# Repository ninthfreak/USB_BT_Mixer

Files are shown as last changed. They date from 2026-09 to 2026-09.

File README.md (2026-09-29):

# USB_BT_Mixer

A small box with two USB-C inputs and one Bluetooth audio output. Any USB-C host that supports USB audio sees each input as a normal USB sound card. The box mixes both inputs and streams the mix to any Bluetooth audio sink.

- **Architecture (start here): [`docs/architecture.md`](docs/architecture.md)**
- Decision log: [`docs/decisions.md`](docs/decisions.md)
- Design record: [`docs/HANDOFF.md`](docs/HANDOFF.md)
- Corrections since the handoff: [`docs/review-notes.md`](docs/review-notes.md)
- Design envelope (limits and extension points): [`docs/design-envelope.md`](docs/design-envelope.md)
- Viability review: [`docs/viability-review.md`](docs/viability-review.md)
- Parts list: [`hardware/BOM.csv`](hardware/BOM.csv)

Status: planning. Inputs: Waveshare RP2350-USB-C ×2, USB-C exposed directly through the enclosure (each needs an external Schottky to the shared rail). Bluetooth output: original ESP32 on a Waveshare ESP32-DEV-KIT-WROOM-32E-N4, powered from the rail via its `VSYS` pin. The ESP32 mixes and owns the audio clock. Configured from any browser via a page the box serves over USB; no case buttons. See [`docs/decisions.md`](docs/decisions.md). Firmware not started; the enclosure test coupon needs re-measuring for the new input board.

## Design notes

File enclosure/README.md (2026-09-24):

# Enclosure

## Status

| Part | State |
|---|---|
| USB-C wall + cradle **test coupon** (`usb_wall_test.scad`) | Ready to print. Two dimensions still need measuring. |
| Full enclosure | Not started. It waits on the coupon results and the TSA5001's dimensions. |

## Test coupon

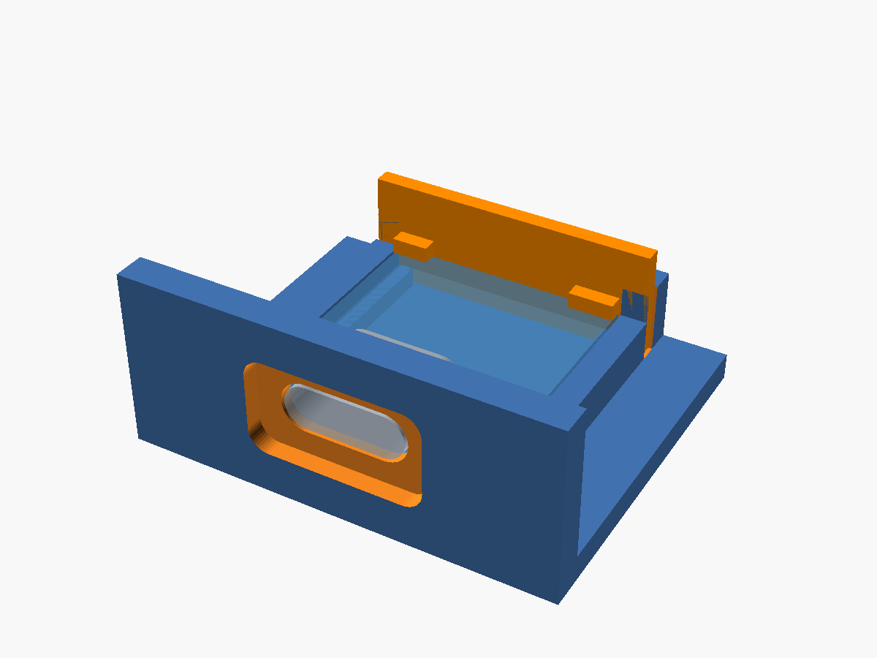
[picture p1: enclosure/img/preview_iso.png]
Coupon with clip, outside view


**What it's for:** a small print to check the port design before the full box.

- Does the QT Py's USB-C shell line up with the wall opening?
- Do real cables seat fully?
- Do plug-in and pull-out forces go into the printed parts instead of the board's solder joints?

**How it holds the board:**

| Force | Taken by |
|---|---|
| Pull-out (cable yanked outward) | The board's front edge presses against the wall's inside face |
| Push-in (plugging in) | The drop-in clip (`key`) behind the board's back edge |
| Up/down wiggle, front | The USB shell sitting in the wall opening |
| Up/down, back | The clip's two corner lips over the board top |
| Side to side | Pocket side walls, flush with the board top so the edge pads stay reachable for soldering |

**Cross-section through the port centreline.** Grey = cut faces, blue = coupon beyond the cut, orange = clip lip.

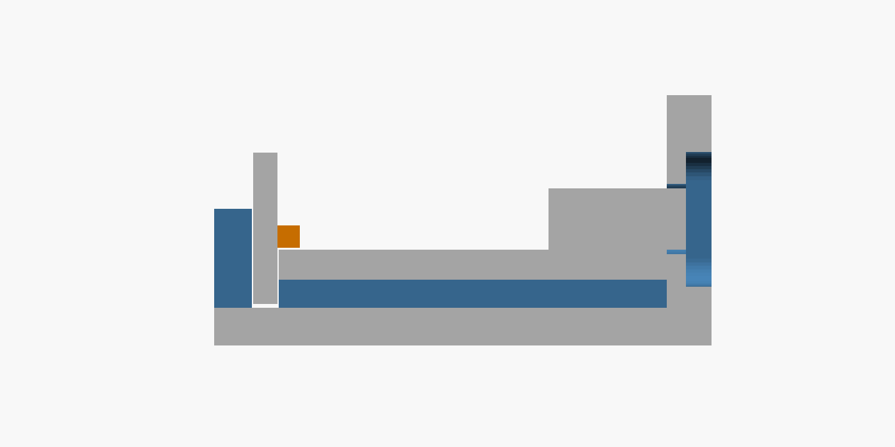
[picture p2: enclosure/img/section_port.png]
Section


## Before printing: measure two values

These aren't in Adafruit's board file. I used typical values; calipers on your board settle them.

| Parameter in `usb_wall_test.scad` | Current value | What to measure |
|---|---|---|
| `pcb_t` | 1.60 mm (assumed) | Board thickness, away from any parts |
| `usb_h` | 3.26 mm (typical top-mount shell) | USB-C shell height, board top to shell top |

After editing them:

1. Run `tests/check_fit.sh`. Every line should say `ok`, `clear` or `contact only`, and the exit code should be 0.
2. Re-export both parts:

   ```
   openscad -o stl/usb_wall_test_coupon.stl -D 'part="coupon"' usb_wall_test.scad
   openscad -o stl/usb_wall_test_key.stl    -D 'part="key"'    usb_wall_test.scad
   ```

   (`fit_checks.scad` repeats the board numbers; update them there too.)

Every other board dimension comes from Adafruit's Eagle `.brd` file: the outline, USB-C position, how far the shell overhangs the board edge (1.03 mm), and the part positions.

## Printing

| Setting | Suggestion |
|---|---|
| Files | `stl/usb_wall_test_coupon.stl`, `stl/usb_wall_test_key.stl` |
| Orientation | As exported. The coupon sits on its base; the clip lies on its back with the lips up. |
| Supports | None. The port opening and pocket are short bridges (~9–13 mm). |
| Material | PLA or PETG for the test. **Not** carbon-fibre-filled (that rule matters most near the antenna in the final box). |
| Layer height | 0.12–0.16 mm gives a cleaner port opening; 0.2 mm is fine for a first look. |
| Walls | 3 or more perimeters |

## Test steps

1. Lower the board into the cradle about 1.5 mm back from the wall.
2. Slide it forward until the USB shell enters the opening and the board edge touches the wall.
3. Drop the clip into the two slots behind the board.
4. Plug in several different cables, including one with a thick plug housing. Check each one:
   - Does it click fully in?
   - Does the board move?
   - Does the plug housing hit the wall before the plug is fully in?
5. Wiggle a plugged-in cable up, down and sideways. Watch whether the board flexes.

## Tuning parameters

| Symptom | Change |
|---|---|
| Board too tight or loose in the pocket | `fit` (default 0.20 per side) |
| Shell binds in the opening, or the gap looks sloppy | `hole_c` (default 0.25 per side) |
| Plug housing hits the wall before the plug is fully in | Raise `om_w` / `om_h` (13.0 × 7.2), or set `mouth_recess` negative |
| Clip too tight or loose in its slots | `key_fit` (default 0.15) |
| Board rattles up and down at the back | Reduce the gap between the clip lip and the board (`pcb_t + 0.1` in `key()`) |

## Files

| File | Contents |
|---|---|
| `usb_wall_test.scad` | Parametric model. Set `part` to `preview`, `coupon` or `key`. |
| `stl/` | Exported print files |
| `tests/check_fit.sh` | Collision checks: coupon, clip, board, USB shell, STEMMA connector, and the install path. Needs `openscad` and Python `trimesh`. |
| `img/` | Preview renders |

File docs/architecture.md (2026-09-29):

# System architecture

How the box works end to end. This is the single reference for firmware work. Decisions behind it are in `docs/decisions.md`; pins are in `hardware/wiring.md`.

**Status:** agreed design (2026-09-28; boards changed 2026-09-29). Nothing is built or tested yet.

```
                ┌────────────── RP2350-USB-C (×2, identical) ─────────────────┐
 Host ──USB──▶  │ sound card (UAC2) ──▶ audio buffer ──▶ PIO I2S out ─────────┼──DOUT──▶ ┐
                │                                         ▲ clocked by ESP32   │         │
                │ config page (USB network, HTTP) ◀─▶ relay ◀─▶ UART ────────┼──TX/RX─▶ │
                └──────────────────────────────────────────────────────────────┘         │
                                                      BCLK/LRCK ◀──────────────────────┤
                                                                                        ▼
                ┌────────────── ESP32-DEV-KIT-WROOM-32E-N4 ───────────────────────────────┐
                │ I2S0 / I2S1 in ──▶ per-input gain ──▶ sum ──▶ limiter ──▶ SBC ──▶ Bluetooth│
                │ UART1 / UART2 ◀─▶ command handler ◀─▶ settings (saved in flash)           │
                │ generates BCLK/LRCK (the only audio clock)                                 │
                └────────────────────────────────────────────────────────────────────────────┘
```

## 1. Roles

| Board | Job | Holds state? |
|---|---|---|
| **Waveshare RP2350-USB-C** (×2, one firmware image) | USB sound card for its host; sends that audio to the ESP32 over I2S, following the ESP32's clock; serves the configuration page over a USB network link; relays commands and replies between page and ESP32 | **No.** Stateless relay and web server. |
| **Waveshare ESP32-DEV-KIT-WROOM-32E-N4** | The only audio clock; receives both inputs; per-input gain, mix, limiter; Bluetooth A2DP source (SBC); pairing and reconnection; command handler | **Yes: the single source of truth** for all settings and pairings, saved in flash |

## 2. Audio path

1. **Host → input board:** USB audio (UAC2, asynchronous with a feedback endpoint), **44.1 kHz** stereo. **Constraint:** stock ESP-IDF's A2DP source is 44.1 kHz only, and nothing in the box resamples (review-notes #16). The audio arrives in 1 ms packets.
2. **Input-board buffer:** a TinyUSB FIFO held at about half full, roughly 2 ms (verified: TinyUSB `AUDIO_FEEDBACK_METHOD_FIFO_COUNT`).
3. **Input board → ESP32:** a PIO program shifts samples out on DOUT **on the ESP32's BCLK/LRCK edges**. The input board never generates audio timing.
4. **ESP32 input:** I2S0 (master) receives input board 1; I2S1 (slave, on looped-back clocks) receives input board 2. Both boards follow the same LRCK edges, so their samples arrive aligned.
5. **ESP32 processing:** host volume × box trim per input → sum in 32-bit → limiter → SBC encoder → Bluetooth.

**Clock synchronisation (no resampling anywhere):**

- The ESP32's clock drains each input board's FIFO at the ESP32's rate.
- TinyUSB's feedback endpoint reports the FIFO level to the host, which then adjusts its sending rate. Each host ends up locked to the ESP32's clock.
- The Bluetooth stack runs on the same ESP32 crystal.

**No host connected:** the input board is still clocked and sends zeros. That input simply contributes silence.

**Latency owned by the box:** input board FIFO ~2 ms + the ESP32's I2S DMA buffers (keep them small; to be measured) + SBC framing. The Bluetooth link and the headphones' buffer add the rest.

## 3. Control path

**Transport to the host: USB network adapter + a web page served by the box.**

- Each input board adds a USB network interface (CDC-NCM; CDC-ECM as fallback) beside its sound card, running lwIP with DHCP, DNS and an HTTP/WebSocket server. This is based on TinyUSB's `net_lwip_webserver` example.
- The host gets an address from the box. The box hands out **no default gateway**, so the host's internet traffic doesn't route through it.
- You open the page by address or name. Addresses differ per board, e.g. `192.168.7.1` for input 1 and `192.168.8.1` for input 2, plus a DNS name.
- The page is stored in the input board's flash and ships with the firmware, so page and firmware versions always match.
- Any browser works, Safari included. No internet, no other server, no permission prompts.

**Flow of one change:**

1. The page sends a command over the WebSocket, e.g. `set gain input=2 db=-6`.
2. The input board wraps it in a UART message and sends it to the ESP32.
3. The ESP32 validates and applies it, saves it if it's persistent, then **sends the new state out on both UARTs**.
4. Each input board forwards the state to any page it has open. Two pages (one per host) stay in sync.

**Events the input board sends unprompted:**

| Event | Purpose |
|---|---|
| Host volume / mute changed (the sound card's volume control) | The ESP32 applies it, so **all gain lives in one place** |
| Host mounted / unmounted / suspended | Status display; silence handling |
| FIFO underrun / overrun counts | Diagnostics |

**UART link (per input board):**

- About 1 Mbaud, 8N1.
- Framed messages: start byte, length, type, sequence number, payload, CRC.
- Commands that change state get an acknowledgement; the sender retries on timeout.
- Input-board pins: TX GP4, RX GP5 (RP2350 UART1). ESP32: UART1 (GPIO17/16) for input board 1, UART2 (GPIO19/18) for input board 2. Full map: `hardware/wiring.md`.

**Commands the ESP32 should support** (first pass, not final):

| Area | Commands |
|---|---|
| Mix | Per-input trim, per-input mute, master level, limiter on/off/threshold, ducking (optional) |
| Bluetooth | Scan, list results, connect, disconnect, forget, list paired devices, status (connected device, codec settings) |
| System | Get full state, firmware versions (ESP32 and both input boards), protocol version, reboot, reboot an input board into its bootloader |

## 4. Firmware updates

| Board | Method |
|---|---|
| Input board | The page (or `picotool`) sends "reboot to bootloader". The input board then appears as a USB drive; copy the new firmware file (UF2) onto it. |
| ESP32 | Its own USB-C (CH343P, auto-reset). Onboard D3 isolates it from the rail, so the box can stay powered while flashing. OTA over Wi-Fi possible later |

## 5. Risks, highest first

| Risk | Difficulty | Mitigation |
|---|---|---|
| Input-board PIO I2S slave timing | 5/10 | Logic analyzer; test with one board first |
| ESP32 I2S1 following I2S0's looped-back clocks | 5/10 | Test early, before the Bluetooth work |
| Sound card + network adapter as one USB device, across macOS, Linux and Android | 5/10 | Test on each host type early. Fallback: USB MIDI or USB serial for control; the UART protocol is unchanged. |
| RP2350 RAM/CPU for USB audio + lwIP + web server together | 3/10 | Measure; keep the page small and serve it from flash. The RP2350's 520 KB RAM (vs the RP2040's 264 KB) is why the input board changed |
| ESP32-A2DP volume handling | Low: supported (verified) | Use `A2DPNoVolumeControl` to avoid applying volume twice; handle passthrough VOL keys (review-notes #16) |

## 6. Suggested bring-up order

Each step is testable on its own:

1. ESP32 as I2S master → one input board sending a test tone → the ESP32 logs samples (proves the I2S slave path).
2. Add the second input board on I2S1 (proves the dual-input clocking).
3. ESP32 mix → Bluetooth A2DP to headphones with the test tones.
4. Input-board USB sound card → real host audio into the chain (proves feedback / clock lock).
5. UART protocol with a minimal command (e.g. set trim) sent from a serial terminal.
6. USB network + web page on the input board.
7. Shared power, hot-plug, enclosure.

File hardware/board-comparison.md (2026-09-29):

# USB-C RP2040 / RP2350 board comparison (power path)

Checked 2026-09-24; RP2350-USB-C added 2026-09-29.

> **Outcome:** the owner chose the **Waveshare RP2350-USB-C** on 2026-09-29, accepting that it needs an external Schottky per board. See `docs/decisions.md` and review-notes #20. The QT Py analysis below is kept because it still documents what the power path has to achieve.

**What this project needs from a board:**

1. A diode between USB VBUS and a header pin, so both boards can share one rail without connecting the two computers' 5V.
2. 5.1 kΩ CC resistors, so C-to-C cables supply power.
3. A reachable VBUS point, for "is a computer connected" sensing (optional, see below).
4. USB-C at the board edge, so the port can come straight through the enclosure wall.

**How each row was checked:**

- **Schematic:** read from the manufacturer's published schematic file (Eagle `.sch`, cloned from GitHub). The netlist shows the connections directly.
- **Text:** manufacturer text seen through search results. The schematic couldn't be fetched from this environment.
- **Unverified:** no source reached.

## Summary

| Board | VBUS → header diode | CC 5.1k | VBUS tap for sensing | Evidence |
|---|---|---|---|---|
| **Waveshare RP2350-USB-C** (chosen) | **No.** Both USB-C ports' VBUS go straight to the `VSYS` net and the `VSYS` header pin. No diode anywhere on the board. **Needs an external Schottky per board.** | **Yes** (R5/R6 on port 1, R10/R13 on port 2) | `VSYS` header pin (it is VBUS) | Schematic (github.com/waveshareteam/RP2350-USB-C) |
| **Adafruit QT Py RP2040** (superseded) | **Yes:** VBUS → D1 (NSR0320) → `+5V` pin | **Yes** (R12, R13) | JP2 solder-jumper pad (VBUS side) | Schematic |
| **Adafruit KB2040** | **Yes:** VBUS → fuse → D1 (NSR0320) → `RAW` pin | **Yes** (R1, R2) | SJ1 solder-jumper pad | Schematic |
| **SparkFun Pro Micro RP2040** | **Yes:** VBUS → PPTC fuse → D2 Schottky (280 mV) → `RAW` pin | **Yes** (R1, R3) | JP14 "USB solder pads" | Schematic |
| Adafruit Feather RP2040 | Yes, VBUS → MBR540 → VHI. But VHI isn't on a header; only the `USB` pin (raw VBUS) and `BAT` are. | Yes | `USB` pin | Schematic |
| SB Components Micro RP2040 | **No:** USB VBUS goes straight to the `5V` net and header pin | **No:** CC1/CC2 are unconnected in the schematic, so C-to-C cables won't supply power | `5V` header pin (it is VBUS) | Schematic (PDF from github.com/sbcshop/Micro_RP2040, v1.0, 2023-04-28) |
| Waveshare RP2040-Zero | **No.** The 5V pin *is* VBUS. | Unverified | 5V pin | Text |
| Seeed XIAO RP2040 | Unverified. Seeed advises adding your own diode when powering through the 5V pin, which suggests no onboard diode on that path. | Unverified | Unverified | Text (indirect) |
| Pimoroni Tiny 2040 | Unverified | Unverified | Unverified | None |

Solder jumpers JP2 (QT Py) and SJ1 (KB2040) join two *different* nets in the schematic, so they're open by default. That leaves the diode in circuit. Confidence ~90%.

## Consequences for this design

- On the QT Py, KB2040, and Pro Micro RP2040, the handoff's original power idea works as intended. **Tie the two boards' `+5V` / `RAW` pins together.** The onboard diodes combine both USB supplies and the computers never connect to each other.
- **The rail is about 4.25–5.2 V, typically ~4.65 V (estimate; review-notes #18)**: the host's VBUS minus cable drop minus one Schottky drop. Measure it on the built box. The TSA5001 voltage question from the handoff still stands.
- **Each host sees both boards' 10 µF input caps plus the added capacitor.** That's about 20 µF + 22 µF, over the USB 10 µF plug-in limit. Low practical risk (see review-notes #3).
- **VBUS sensing may not be needed.** With the cable unplugged, the board sees no USB frames, and TinyUSB reports "suspended".
  - Firmware can treat "not mounted or suspended" as "contribute zeros". That's the same behavior the handoff wanted from GPIO24.
  - Confidence ~75%. Sensing is still cheap to add from the solder-jumper pad: a 10k/20k divider to a GPIO.

## Recommendation (not a decision), as written 2026-09-24

**QT Py RP2040.** It's small (PCB outline 20.7 × 17.8 mm from the board file; the USB-C shell may overhang), has edge USB-C, and has all three power features confirmed from the schematic. It exposes about 11 GPIOs; this project needs about 6.

## What changed on 2026-09-29

The owner chose the **Waveshare RP2350-USB-C** instead, for its RAM. The comparison above ranks boards by power path alone, which is only one axis.

| | QT Py RP2040 | RP2350-USB-C |
|---|---|---|
| RAM | 264 KB | **520 KB** |
| Flash | 8 MB | 2 MB (W25Q16) |
| PIO blocks | 2 | 3 |
| Size | 20.7 × 17.8 mm | 33.0 × 17.5 mm (sourced, not measured) |
| USB-C ports | 1, at the edge | 2, one at each end. The inner one is unused and stays inside the case |
| Exposed GPIOs | ~11 | 15 (GPIO0–10, 26–29) |
| VBUS diode | Onboard | **External, owner-fitted** |

The deciding factor was RAM: fitting USB audio, lwIP and the web server on one chip is the highest firmware risk in `docs/architecture.md`, and doubling RAM attacks it directly. A missing diode is a part the owner already has; RAM is not.

**KB2040 or Pro Micro RP2040** if you want more pins or bigger solder pads. The Pro Micro's PPTC fuse is a nice extra. Their longer 33 × 18 mm Pro Micro footprint makes wall-mounting slightly easier.

## Sources

- Adafruit QT Py RP2040 design files: https://github.com/adafruit/Adafruit-QT-Py-RP2040-PCB
- Adafruit KB2040 design files: https://github.com/adafruit/Adafruit-KB2040-PCB
- Adafruit Feather RP2040 design files: https://github.com/adafruit/Adafruit-Feather-RP2040-PCB
- SparkFun Pro Micro RP2040 design files: https://github.com/sparkfun/SparkFun_Pro_Micro-RP2040
- SB Components Micro RP2040 schematic: https://github.com/sbcshop/Micro_RP2040
- Waveshare RP2040-Zero wiki: https://www.waveshare.com/wiki/RP2040-Zero
- Seeed XIAO RP2040 wiki: https://wiki.seeedstudio.com/XIAO-RP2040/

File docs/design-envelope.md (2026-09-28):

# Design envelope

The design's limits and extension points in one place. Written 2026-09-25.

**Baseline design (updated 2026-09-28):** 2× QT Py RP2040 (identical I2S slaves) → ESP32 Feather V2 (I2S clock master, mixer, A2DP source) → Bluetooth. One audio clock domain at 48 kHz, owned by the ESP32.

> **Sample rate is 44.1 kHz end to end** (constraint from ESP-IDF's A2DP source; review-notes #16). Any "48 kHz" below refers to the old TSA5001 baseline.
>
> Parts of this page were written for the earlier RP2040-master + TSA5001 baseline. Where it says "board A's clock", read "the ESP32's clock". The TSA5001-specific limits (48 kHz only, codec list) now describe the fallback only; the ESP32 A2DP source is SBC-only, and its sample rate is set in firmware.

**Evidence labels:** *verified* = checked against source, schematic or datasheet; *sourced* = third-party text; *estimate* = my judgment.

---

## 1. Hard limits of the baseline

| Limit | Value | Set by | Evidence |
|---|---|---|---|
| Sample rate | **48 kHz only** | TSA5001 | Sourced |
| USB speed | Full speed (12 Mbit/s) | RP2040 | Verified |
| USB audio bandwidth per input | Stereo 48 kHz at 16 or 24 bits fits easily (≤ 288 bytes per 1 ms frame; full-speed allows up to 1023) | USB 2.0 full-speed isochronous transfers | Calculated |
| Hosts that play 48 kHz material | The host OS converts it to 44.1 kHz itself; the box only offers 44.1 kHz | Host OS | Estimate: macOS, Linux and Android do this automatically |
| Bluetooth output | **One A2DP link, SBC/AAC/aptX family**, no LE Audio or broadcast (Auracast) | TSA5001 | Sourced (vendor list, not verified) |
| Bluetooth sinks at once | Presumably 1 | TSA5001 | Estimate |
| Latency, box's own path | ~2–3 ms | TinyUSB FIFO (~2 ms) + I2S hops (≈21 µs each) | Verified / calculated |
| Latency, end to end | Dominated by the Bluetooth link and the sink's buffer; unknown until measured | Sink + transmitter | — |
| Supply rail | About 4.25–5.2 V, typically ~4.65 V (host VBUS minus cable drop minus one Schottky diode) | Board power paths, USB-C VBUS range | Verified topology; voltage is an estimate (review-notes #18) |
| Power available | Whatever one host's port supplies, since one host may power everything | USB spec: 500 mA for USB 2.0, 900 mA for USB 3.x, 1.5–3 A for USB-C current modes | Sourced (USB spec) |
| Audio back to hosts (microphone) | None | A2DP carries audio one way only; no capture stream is defined | Verified (design) |
| Controls | Each host's own volume slider only | Design | — |

---

## 2. The rule behind most boundaries: one clock domain

Everything mixed digitally must run on **board A's clock**.

| Source type | Fits? | Why |
|---|---|---|
| USB input through another RP2040 | **Yes** | The host follows A's clock through USB feedback. |
| ADC (analog input) | **Yes** | The ADC follows A's clocks. It needs a master clock, which requires the 61.44 MHz clock change. |
| Anything with **its own clock**: S/PDIF/optical input, a Bluetooth *receiver*, network audio, a second I2S master | **No, not without an ASRC** | Two independent clocks drift apart, so one stream has to be resampled (asynchronous sample-rate conversion). That means a hardware ASRC chip or software resampling; difficulty 6–7/10. |

---

## 3. Extension points

| Extension | What it takes | Clock change? | Difficulty | Confidence | Main risk |
|---|---|---|---|---|---|
| **More USB inputs** | Another RP2040 per input, chained before board B. Each adds 1 frame (≈21 µs). | No | 3/10 per board | ~80% | Board A's clock line fans out further; power budget |
| **Analog line input** | 3.5 mm jack → PCM1808 ADC (following A's clocks) → board B's chain input; 12.288 MHz master clock from board A; fix sample scaling; gain in firmware | **Yes: 76.8 → 61.44 MHz** | ~4/10 | ~70% | Ground-loop hum; ADC input range on a 4.25–5.2 V supply (unverified) |
| **Analog line output** | PCM5102A DAC wired in parallel with the TSA5001; 3.5 mm jack | No | ~2/10 | ~85% | Hum into mains-powered gear; wired output is ~150–250 ms ahead of Bluetooth |
| Headphone output | Analog line output + headphone amplifier | No | ~3/10 | ~80% | Same as above |
| Different Bluetooth output stage | Anything that accepts board A's I2S: ESP32 (SBC only), TS3086-based module (if the firmware suits), nRF5340 (LE Audio) | No | 4–8/10 | 30–60% | Firmware and interop; see `viability-review.md` §3b |
| USB Bluetooth dongle (aptX Adaptive) | Third RP2040 as USB audio **host**; board A's clock trimmed to follow the dongle | No, but A's clock becomes adjustable | 7/10 | ~40% | RP2040 host playback unproven; clock-following loop |
| Physical volume knob | Potentiometer → a spare analog pin, or a digital encoder | No | 2/10 | ~85% | **Pin conflict:** A0–A3 (the analog pins) are used for I2S in the current pin map |
| Status LED | Onboard NeoPixel, **not** red/green-coded | No | 1/10 | ~95% | — |

---

## 4. Not reachable without a redesign

| Goal | Why not |
|---|---|
| Sample rates other than 48 kHz end to end | TSA5001 is 48 kHz only |
| Latency below what the sink's buffer allows | The sink's firmware sets it; only a lower-latency codec or transport negotiated with that sink helps |
| Microphone / calls through the headphones | A2DP carries audio one way only |
| Several Bluetooth sinks at once | Not with the TSA5001 |
| Mixing unsynchronised digital sources | Needs an ASRC (§2) |
| Running with no host connected | No battery; the box gets its power from the hosts |

---

## 5. Resource budget, board A (current pin map)

| Resource | Used | Free | Notes |
|---|---|---|---|
| Header GPIOs (11, plus 2 on the STEMMA QT connector) | BCLK, LRCK, DOUT, DIN, UART TX | ~6–8 | GP24/25 are the clock-output-capable pins needed for an ADC master clock |
| PIO state machines (8) | ~2–3 (I2S out, I2S in) | ~5 | A separate DAC data line would use one more |
| CPU | TinyUSB + mixing + limiter | Large margin (estimate) | ~1,600 cycles per 48 kHz frame at 76.8 MHz, ~1,280 at 61.44 MHz |

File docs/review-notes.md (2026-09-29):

# Review notes on the handoff

Checked 2026-09-24. These are corrections and added risks. The items are *not* yet verified on hardware.

## 1. Board choice: the handoff says Pico, the plan was a USB-C RP2040 board

- The handoff specifies a micro-USB Raspberry Pi Pico plus panel extensions. The real plan was a **USB-C RP2040 board** (Waveshare, Adafruit, or Seeed), with its **port exposed directly through the enclosure wall**. No extension cables.
- Anything in the handoff that depends on the Pico board is suspect:
  - **Power sharing:** the Pico has an onboard VBUS → VSYS Schottky. Other boards may tie their 5V pin straight to VBUS. If so, tying the two boards' 5V pins together **connects both computers' 5V rails**. Each board then needs its own external Schottky.
  - **VBUS sense:** GPIO24 is Pico-only. Plan on a resistor divider from each board's VBUS (before any diode) to a spare GPIO.
  - **CC resistors (5.1 kΩ Rd):** needed for C-to-C cables to supply power. Most USB-C boards have them. Verify per board.
- Enclosure impact: the board's USB-C receptacle takes the plug forces directly. The enclosure must back the board so that plugging and unplugging don't load the solder joints.

## 2. System clock: 153.6 MHz is an overclock

| Clock | × BCLK | RP2040 (Pico) rating 133 MHz | RP2350 (Pico 2) rating 150 MHz |
|---|---|---|---|
| 76.8 MHz | 25 | In spec | In spec |
| 153.6 MHz | 50 | Over spec (SDK 2.1.1+ treats up to 200 MHz as supported, ~85% sure of that) | ~2% over spec |

- **Recommendation:** start at **76.8 MHz** (VCO 768 MHz, /5 /2). It divides evenly, and it's in spec on both chips.
- A slave PIO still gets ~12 cycles per BCLK half-period, which is enough to follow edges.
- Move to 153.6 MHz only if CPU time runs short.
- Note: jitter here doesn't affect sound quality (the TSA5001 re-encodes digitally). The integer divider mostly helps cleaner analyzer captures.
- Confidence: ~80% that 76.8 MHz leaves enough CPU for TinyUSB plus mixing. The load is light (48k stereo frames/s).

Full list of integer options from the 12 MHz crystal (≤ 210 MHz): 30.72, 46.08, 61.44, 76.8, 153.6 MHz.

## 3. Rail capacitance vs. the USB spec

- USB 2.0 caps plug-in capacitance at **10 µF** unless you limit inrush current. The handoff says ≤ 47 µF.
- Each host sees all the VSYS capacitance through its diode: Pico A's + Pico B's onboard caps + the added capacitor.
- **Practical risk: low.** Most hosts tolerate it. At worst you'd see a brief brown-out or a port-overcurrent message on plug-in.
- **Recommendation:** start at 22 µF. Go up only if the TSA5001 drops out under load.

## 4. Firmware: only connect USB when VBUS is present

- Pico B gets power from Pico A's side even when its own cable is unplugged.
- Firmware should call `tud_connect()` only while GPIO24 reads high, and `tud_disconnect()` when it goes low. Otherwise it drives the D+ pull-up into a dead cable.
- Low risk either way, but it's cleaner.

## 5. Pico 2 (RP2350) erratum E9

- On RP2350 A2 silicon, an input pin with the **internal pull-down** enabled can latch at ~2 V.
- It doesn't affect pins driven by Pico A or tied hard to GND.
- If you use Pico 2 boards, **disable internal pull-downs** on the I2S input pins.
- Confidence: ~85% that it's harmless in this design with pulls off.

## 6. RP2040-Zero power path (board under consideration)

- **Source-verified:** on the RP2040-Zero, the **5V pin is wired straight to USB VBUS**, with no diode. The board has no power-path circuitry, only the ME6211 3.3 V LDO. (Waveshare wiki text, seen through search results. The schematic PDF couldn't be fetched from this environment.)
- **Consequence:** the handoff's "tie the two VSYS pins together" becomes "tie two computers' VBUS together". **Don't do it.**
- **Consequence 2:** Board A is the only clock source and the only output. If only Board B's cable is plugged in, Board A must still get power, so a shared rail is required.
- Candidate fixes are in the chat log and not yet chosen. Test to run: power one Zero's 3V3 pin from a bench supply with USB unplugged, and measure the 5V pin. That shows whether the ME6211 back-feeds VBUS.
- **CC resistors:** not verified. Test with a C-to-C cable into a laptop.

## 7. Board comparison

See `hardware/board-comparison.md`. The QT Py RP2040, KB2040, and Pro Micro RP2040 all have an onboard VBUS diode and CC resistors (confirmed from schematics). The shared-rail power design works on them as originally intended.

## 8. Board chosen: Adafruit QT Py RP2040

Sections 4–6 above that assume a Pico or Pico 2 are superseded:

- GPIO24 VBUS sense → optional divider from JP2, or firmware-only detection (see `hardware/board-comparison.md`).
- Erratum E9 (#5) → moot. The QT Py is RP2040, not RP2350.
- Wiring → `hardware/wiring.md`.

## 9. Volume control: omitting it likely breaks macOS

- The handoff says to leave the volume control out of the USB descriptor and let the OS apply software volume.
- **Windows** does that. **macOS generally doesn't.** It greys out the volume slider for devices that expose no volume control (the same as with HDMI). Confidence ~85%.
- **Recommendation:** keep the Feature Unit (volume + mute), as TinyUSB's `uac2_speaker_fb` example already does, and apply the gain per board in firmware. Each computer's slider then still sets its level in the mix.
- Difficulty 2/10.

## 10. TinyUSB feedback: verified against current source

Checked against the TinyUSB master branch cloned 2026-09-24:

- The `uac2_speaker_fb` example exists.
- The buffer-fill method is `AUDIO_FEEDBACK_METHOD_FIFO_COUNT`, set in `tud_audio_feedback_params_cb()`. It holds the FIFO at half full and adds about 2 ms of delay. The header comment says it's tested on Windows, Linux, and macOS.
- **The Windows feedback-format worry is mostly handled.** For UAC2, TinyUSB sends 16.16 feedback in 4 bytes, which is the format Windows requires.
- Keep "test on Windows" as a milestone, but it's lower risk than the handoff implied.

## 11. Debug output: use the UART, not USB serial

- The handoff's milestone 1 logs over "serial". On the QT Py, the only USB port is the audio port.
- **Recommendation:** log on UART TX (GP20) to a 3.3 V USB-serial adapter. That keeps the audio USB descriptor simple.
- USB CDC plus audio (composite) also works, but it adds another thing to debug on Windows.

## 12. Smaller gaps

| Item | Note | Risk |
|---|---|---|
| Firmware updates with the box closed | The BOOT button is inside the box. Add a TinyUSB reset interface so `picotool reboot -u` (or a 1200-baud touch) enters the bootloader. Consider a pinhole over the button as a backup. | Low |
| NeoPixel | Drive GP11 low to keep it off (a few mA and stray light), or use it as a status LED, **not** red/green-coded. | Low |
| USB suspend current | If one host sleeps while the other plays, the diode-OR can still draw ~100 mA from the sleeping host. That's technically over the 2.5 mA suspend limit. Hosts rarely enforce it. | Low |
| Ground tie | The box joins both computers' grounds. The box's audio is digital so it's fine here, but either computer's *own* analog outputs could pick up hum. | Low |
| Per-stage delay | Each slave stage adds 1 frame (≈21 µs). Negligible. | None |
| PCM5102A test board | Many modules need SCK tied to GND (a solder jumper) to run without MCLK. Check before milestone 2. | Low |

## 13. ESP32 switch: power and pin effects (2026-09-28)

- **Power:** the ESP32 streaming Bluetooth adds roughly 100–150 mA (estimate), more with Wi-Fi. The box total is about 150–300 mA (estimate), still within one USB 2.0 port's 500 mA. Raise `bMaxPower` in each RP2040's USB descriptor to about 300–400 mA.
- **Feather V2 feed:** superseded by #14 (rail → `BAT` pin, no diode).
- **Pins:** the QT Py's only UART pair (GP20 TX / GP5 RX) is needed for the RP2040 → ESP32 control link. RP2040 debug logging moves to a PIO-based serial output on a spare pin. This supersedes #11. `hardware/wiring.md` needs updating once the mixing location is decided.

## 14. Feather V2 power path (verified from Adafruit's schematic, 2026-09-28)

Source: `Adafruit ESP32 Feather V2.sch` from github.com/adafruit/Adafruit-ESP32-Feather-V2-PCB.

| Net | Connected to |
|---|---|
| VBUS (Feather's USB-C) | `USB` header pin **directly**, CP2102N USB-serial chip, MCP73831 charger input, Schottky D4 (MBR540) → VHI |
| VBAT | `BAT` header pin, JST socket, charger output, P-MOSFET Q3 → VHI |
| VHI | Input to both AP2112 3.3 V regulators |
| Q3 gate | VBUS (battery path turns off when USB is present) |
| CC1 / CC2 | 5.1 kΩ each |

**Decision input: feed the shared rail into `BAT`, not `USB`. No external diode.**

- **Feeding `USB` would put the rail on the Feather's own USB-C VBUS.** A laptop plugged in for flashing would then see voltage already present (USB-C sources expect ~0 V before switching on), and an unpowered laptop port would be back-fed.
- **Feeding `BAT`:** the rail reaches the regulator through Q3 (and its body diode). Nothing reaches VBUS, so flashing cables behave normally. When a flashing cable is plugged in, Q3 switches off and USB powers the ESP32.
- **Charger behaviour:** with the box powered, the rail (typically ~4.65 V; range in #18) is above the charger's 4.2 V target, so it doesn't charge. With the box *unpowered* and a flashing cable in the Feather, the charger sources ≈200 mA into the rail. **Correction (see #17):** that's probably not enough to run the whole box, so the QT Pys may brown out during bench flashing.
- **Limits to respect:** never connect a LiPo to the JST socket. The rail on `BAT` exceeds a LiPo's 4.2 V maximum. The ESP32's battery-voltage input (through the 200 kΩ divider) will read the rail voltage, which is a useful diagnostic.
- Confidence ~80%. The topology is verified. The charger's reverse behaviour and its absolute-maximum VBAT rating (believed ≥6 V) are from memory.

## 15. Architecture change: ESP32 hub (2026-09-28)

These parts of the handoff no longer apply: RP2040 A as clock master and mixer; the `ROLE_MASTER_LAST` / `ROLE_SLAVE` split; the TSA5001 output.

- **RP2040 firmware:** one role on both boards. USB audio in → I2S slave out, plus the UART control relay. Each board keeps a DIN chain input for future expansion.
- **RP2040 system clock:** no longer needs to divide evenly into the audio clock, because the RP2040s receive the clock instead of making it. Its only job is to follow BCLK edges reliably (76.8 MHz or 125 MHz both fine; estimate).
- **ESP32:** I2S0 master (receives QT Py 1) and I2S1 slave on looped-back clocks (receives QT Py 2). The mix, per-input gain and limiter run in ESP32 firmware. The ESP32's audio PLL (APLL) should give an accurate 48 kHz (estimate).
- **ESP32 I2S DMA buffering** adds latency. Keep the DMA buffers small; to be measured.
- **Analog input option (if revisited):** a PCM1808 master clock would now come from the ESP32 (which can output a master clock on GPIO0/1/3 only, ~80% confident; none of those is on the Feather's headers). Revisit if needed.

## 16. ESP32-A2DP library and ESP-IDF A2DP source: verified from source (2026-09-28)

Sources: `pschatzmann/ESP32-A2DP` at commit 35bace5 (2026-09-22); `espressif/esp-idf` master (2026-09-25), `components/bt/host/bluedroid/btc/profile/std/a2dp/bta_av_co.c`.

### Reconnection: supported

- The last connected headphone address is **saved in flash** (NVS key `src_bda`) on connect, and loaded again at start.
- `set_auto_reconnect(true, retries)` retries that address after a disconnect and on a periodic heartbeat. When the retries run out, it falls back to scanning.
- **Scanning only connects to a device your code accepts**, through a name list or `set_ssid_callback(...)`. Our firmware should use the callback to *collect* scan results for the web page rather than auto-accepting.
- A deliberate `disconnect()` suppresses auto-reconnect. "Forget" = clear the saved address (`clean_last_connection`), plus remove the bond with ESP-IDF's `esp_bt_gap_remove_bond_device` (ESP-IDF API; not checked in this pass).

### Headphone volume buttons: supported, with one fix needed

Headphones report button presses in one of two ways:

| How the headphones report it | What the library does | What our firmware must do |
|---|---|---|
| **Absolute volume** (AVRCP 1.4+): the headphones change their own volume and notify the source | Receives the notification, echoes the value back, **and also scales the audio samples itself** (default `A2DPDefaultVolumeControl`) | **Install `A2DPNoVolumeControl`** (`set_volume_control`). Otherwise the volume is applied twice: once in the headphones and again in the ESP32, so it drops off far faster than intended (estimate). Report the level to the page. |
| **Passthrough VOL_UP / VOL_DOWN keys** (headphones act as a remote) | Passes key codes to `set_avrc_passthru_command_callback` only; **takes no action itself** | Handle the keys: step the box's master gain |
| Headphones set the *source's* volume directly (rare) | Logged, ignored | Nothing, unless a real headphone needs it |

If the headphones do neither, they adjust their own volume locally, and nothing is needed.

### Sample rate: **44.1 kHz only** (ESP-IDF limitation)

- ESP-IDF's A2DP **source** advertises SBC at **44.1 kHz only** (`bta_av_co_sbc_caps.samp_freq = A2D_SBC_IE_SAMP_FREQ_44`). Its sink side offers 48 and 44.1 kHz. The library README also says the source expects 44.1 kHz PCM.
- **Consequence: the whole box runs at 44.1 kHz. This is a constraint, not an option.** The ESP32 I2S master runs at 44.1 kHz, and the QT Pys advertise 44.1 kHz on USB. The hosts resample 48 kHz material themselves (macOS, Linux and Android do this automatically; estimate ~90%). The box itself still needs no resampling.
- Patching ESP-IDF's capability table to offer 48 kHz is an experiment, not a design option: it needs a maintained patched ESP-IDF and is untested (~50%). Resampling 48 → 44.1 kHz in the ESP32 would break the one-clock, no-resampling design rule.
- The earlier 48 kHz figures (the handoff's TSA5001 plan, the RP2040 clock maths) no longer apply to this design.

### Other findings

- **Headphone latency reporting:** ESP-IDF ≥ 5.3 delivers `ESP_A2D_REPORT_SNK_DELAY_VALUE_EVT` when the headphones report their own delay. The library only logs it, but our firmware can show it on the page. It helps with the latency question.
- **Codecs:** the library's AAC support is for the *receiving* (sink) side only. The source is SBC.
- **Build:** usable as an ESP-IDF component (CMakeLists present). It lists `arduino-audio-tools` as a required component despite the README saying there are no other dependencies. That's minor build friction.
- **Licence ambiguity:** the LICENSE file is Apache-2.0, but a CMakeLists comment says GPLv3. Irrelevant for a personal build; check before distributing anything.

## 17. Feather V2 on the rail: full power check (2026-09-28)

| Check | Result | Evidence |
|---|---|---|
| Path: rail → `BAT` → Q3 P-MOSFET → VHI → AP2112 3.3 V regulator | Works. Q3's gate sits at VBUS (0 V without the Feather's own USB cable), so Q3 turns fully on. | Schematic (verified) |
| Regulator input limit | Rail ~4.25–5.2 V (#18) vs AP2112 maximum 6 V. OK. | AP2112 datasheet via search |
| Regulator headroom | Needs ≥ ~3.55 V in (250 mV dropout). Rail gives ~0.7 V of margin at its low end (4.25 V), ~1.1 V typical. OK. | Datasheet via search + calculation |
| Regulator heat | ESP32 streaming ~150–250 mA (estimate) × (rail − 3.3 V): ≈ 0.2–0.35 W typical, up to ≈ 0.3–0.5 W at the 5.2 V high end, in a SOT-23-5. **Same as the Feather's own USB power:** that path is also VBUS minus one Schottky (D4), so the regulator sees the same voltage either way. Not re-checked against the AP2112's thermal resistance. *(Corrected: an earlier version said the rail was "better than USB's 5 V"; the regulator never sees 5 V from USB either.)* | Estimate + schematic |
| Battery-voltage monitor (200 kΩ divider to an ADC pin) | Reads half the rail: ~2.1–2.6 V at the pin. Safe; a free rail-voltage readout. | Schematic + calculation |
| **MCP73831 charger chip (U3) with the rail (~4.25–5.2 V) on its battery pin** | **Soft spot.** Its absolute-maximum table lists all pins as −0.3 V to (VDD + 0.3) V. Taken literally, that's also exceeded by every battery-powered Feather with no USB (4.2 V battery, VDD = 0), so it can't be the whole story. The chip is designed to sit on a battery while unpowered. But the rail is typically ~0.45 V and at worst ~1.0 V above the 4.2 V it's designed around (#18), and I couldn't reach the full datasheet to check. **~75% harmless (estimate; lowered from 80% once the rail's high end was worked out).** | Datasheet row via search; full datasheet blocked |
| Charger back-feeding the rail when the box is unpowered and a flashing cable is in the Feather | The charger sources ~200 mA (R4 = 5.1 kΩ) into the rail. That's **probably not enough to run the QT Pys too** (box ≈ 150–300 mA), so they may brown out and restart during bench flashing. Harmless but messy. **Corrects #14**, which said it would "power the whole box". The ESP32 itself is fine; it's powered from USB through D4. | Calculation |

**Ways to remove the charger concern:**

| Option | Effect | Difficulty | Recommendation |
|---|---|---|---|
| **A. Remove the charger chip (U3, SOT-23-5)** from the Feather | Removes both the voltage question and the back-feed. The Feather works normally without it; it only charges batteries. | 2/10 with hot air or two irons; permanent | **Recommended** (not a decision) |
| B. One Schottky diode, rail → `BAT` | BAT drops by another ~0.3–0.4 V: typically ~4.3 V, range ~3.9–4.9 V. Regulator still has headroom at the low end. The back-feed is blocked | 1/10 | Reduces the concern but doesn't remove it. Still a non-battery source on `BAT` with the charger fitted, which Adafruit warns against (#19) |
| C. External 3.3 V regulator into the Feather's `3V` pin, Feather `EN` pulled low | Charger and `BAT` unused entirely | 3/10 | Works, but the ESP32 then can't be flashed unless the box is powered |
| D. Leave as is | **Against Adafruit's guidance** (#19). Earlier rated ~75% fine; that estimate no longer stands | 0/10 | Not recommended |

## 18. Rail voltage: derived, not assumed (2026-09-28)

**Correction.** Every doc called the shared rail "~4.6–4.8 V". That figure came from the handoff, was never derived, and was presented as the range. It is only a typical value. Where "4.6–4.8 V" or "4.7 V" still appears, read the range below. `HANDOFF.md` is left verbatim as the historical record.

**Rail = host VBUS − cable drop − QT Py diode drop (D1, NSR0320).** The pin is labelled `5V` but is never 5 V from a 5 V host.

| Input | Value | Evidence |
|---|---|---|
| Host VBUS (USB-C, vSafe5V) | 4.75–5.5 V allowed; most hosts ~5.0–5.1 V | Range: sourced (USB Type-C spec, via search). Typical: estimate |
| Cable drop at ~0.15–0.3 A | ~0.05–0.1 V | Estimate |
| NSR0320 forward drop | 0.24 V typ at 10 mA; 0.5 V max at 900 mA | Sourced (datasheet figures via search; onsemi PDF blocked here) |
| NSR0320 drop at the box's current (~0.15–0.3 A, estimate) | ~0.3–0.4 V | Estimate, interpolated between the two datasheet points |

| Case | Calculation | Rail |
|---|---|---|
| Low: host at spec minimum, long cable, full box load through one diode | 4.75 − 0.1 − 0.4 | **~4.25 V** |
| Typical | 5.05 − 0.05 − 0.35 | **~4.65 V** |
| High: host at spec maximum, light load | 5.5 − 0 − 0.3 | **~5.2 V** |

**Result: about 4.25–5.2 V, typically ~4.65 V. Confidence in the range ~75%** (the diode curve between 10 mA and 900 mA and real host voltages are the soft parts).

When both hosts are connected, the host with the higher VBUS supplies most or all of the current (the two diodes act as an OR). Current doesn't split evenly.

**Effects of the wider range:**

| Part | Low end (4.25 V) | High end (5.2 V) |
|---|---|---|
| Feather AP2112 regulator (needs ≥ ~3.55 V, max 6 V) | OK | OK |
| Regulator heat | Lower | Higher, but equal to the Feather's normal USB power (VBUS − D4) at the same host voltage |
| Feather battery monitor ADC (half the rail) | ~2.1 V | ~2.6 V; safe |
| MCP73831 charger (U3) battery pin | Concern mostly gone | ~1.0 V above 4.2 V; the concern gets worse (see #17 options) |
| QT Py's own 3.3 V regulator | Not re-checked here; it's the board's normal USB-powered condition | Same |

**To verify:** measure the rail with a multimeter on the built box: one host, then both, at idle and while streaming Bluetooth. Record it in `docs/` as a test log.

Sources: [USB Type-C Spec R2.0](https://www.usb.org/sites/default/files/USB%20Type-C%20Spec%20R2.0%20-%20August%202019.pdf); [onsemi NSR0320MW2T1 datasheet](https://www.onsemi.com/download/data-sheet/pdf/nsr0320mw2t1-d.pdf).

## 19. Adafruit's guidance on powering a Feather through `BAT` (2026-09-28)

**Adafruit advises against it.** Their Feather power-management pages carry the same warnings across the family:

- "Do not use alkaline or NiMH batteries and connect to the battery port - this will destroy the LiPoly charger" (and, on several pages, "there's no way to disable the charger").
- "The Feather is not designed for external power supplies."
- Their suggested alternatives: USB power (wall adapter or USB battery pack), or a 5 V source wired to a USB cable. Feeding 3.3 V into the `3V` pin is listed as technically possible but **not recommended**.

| Claim | Evidence |
|---|---|
| The warnings above appear on Adafruit's Feather power-management pages (ESP32-S2, ESP32-S3, HUZZAH32, RP2040, M0, 32u4 and others) | Sourced: search-result text; learn.adafruit.com is blocked here, so not read directly |
| The ESP32 Feather V2 page carries the same warning | **Not confirmed.** The V2 text pasted by the owner has a "Danger:" box whose contents were stripped. Very likely the same family text (estimate ~85%) |
| Why the charger is destroyed | **Not stated by Adafruit.** Unknown whether a 4.25–5.2 V supply triggers the same failure as a 3–4.5 V alkaline pack |

**What this changes:**

- The failure Adafruit names is **the charger chip (U3)**, which is exactly the part #17 flagged. Their warning backs up that concern and replaces my ~75% estimate.
- **Option A (remove U3)** takes away the part Adafruit says gets destroyed. After removal, "no way to disable the charger" no longer applies. It is still outside Adafruit's supported use; I found no Adafruit statement about a Feather with U3 removed.
- **Options B and D** leave U3 in place with a non-battery source on `BAT`. Both go against Adafruit's guidance.
- **Option C** (3.3 V into `3V`, `EN` pulled low) is Adafruit's "not recommended, technically possible" path.
- **Feeding the Feather's `USB` pin** is Adafruit's closest supported route, but #14 already rejected it: it back-feeds the Feather's own USB-C port.

**Recommendation (not a decision): option A**, now with a documented reason beyond my estimate. Confidence that the Feather runs normally from `BAT` with U3 removed: ~85% (it follows from the schematic, but I haven't seen it reported or endorsed by Adafruit).

## 20. Board change: RP2350-USB-C inputs and a Waveshare ESP32 dev kit (2026-09-29)

Both boards changed. Sources: Waveshare's `RP2350-USB-C.pdf` (github.com/waveshareteam/RP2350-USB-C) and `ESP32-DEV-KIT-XX.pdf`, both read directly; Espressif's ESP32 datasheet v5.3.

### Why the ESP32 board changed

The Feather V2 has **no supported way to take a non-battery supply** (#19). Every route was outside Adafruit's guidance or needed board surgery. The owner chose a board designed for rail power instead of picking one of options A–D in #17.

| Check (Waveshare ESP32-DEV-KIT-WROOM-32E-N4) | Result | Evidence |
|---|---|---|
| Rail → `VSYS` header pin (J3-19) → MP1605 converter → 3V3 | Works. Schematic notes "VIN: 2.3–5.5 V, Iout max 2 A" against our 4.25–5.2 V rail | Schematic (verified) |
| Back-feeding its USB-C | **Blocked by D3** (MBR230) between VBUS and VSYS. The rail never reaches its USB-C, so **the ESP32 can be flashed with the box powered** | Schematic (verified) |
| ETA6098 charger on the same VSYS net | Its input is VSYS and its battery pin sits below that through Q2 — the opposite of the Feather's problem, where the battery pin sat *above* an unpowered input. With no battery fitted it should stay idle | Schematic (verified); idle behaviour is an estimate, ~85%. Its absolute-maximum ratings are unverified |
| Chip is original ESP32 (Classic BT needed for A2DP) | Yes: ESP32-WROOM-32E. "Bluetooth v4.2 BR/EDR and Bluetooth LE" | ESP32 datasheet v5.3 (verified) |
| 3.3 V current | Datasheet recommends "500 mA or more"; the MP1605 is rated 2 A | Both datasheets (verified) |

Two onboard uses forced a pin-map redo: **GPIO27** drives the WS2812 RGB LED through R1 (0 Ω) and **GPIO34** carries the battery-voltage divider through R28 (0 Ω). New map in `hardware/wiring.md`.

### Why the input board changed

RAM. The RP2350 has 520 KB against the RP2040's 264 KB, and "USB audio + lwIP + web server on one chip" is the highest firmware risk in `docs/architecture.md`.

| Check (Waveshare RP2350-USB-C) | Result | Evidence |
|---|---|---|
| VBUS → header diode | **None.** Both USB-C ports' VBUS connect straight to `VSYS` and the `VSYS` header pin. The schematic contains no diode at all | Schematic (verified) |
| Consequence | Tying two boards' `VSYS` pins together would connect the two hosts' 5 V rails. **One external Schottky per board is mandatory**, `VSYS` → rail, cathode to the rail | Analysis |
| CC resistors | 5.1 kΩ on both ports (R5/R6, R10/R13) | Schematic (verified) |
| Its own regulator | RT9013-33 (500 mA), fed from VBUS *before* our diode, so it keeps full headroom | Schematic (verified) |
| Flash | W25Q16 = **2 MB**, down from the QT Py's 8 MB. Ample for firmware plus a small page | Schematic (verified); "ample" is an estimate |
| TinyUSB on RP2350 | Supported: RP2350 platform handling in the rp2040 port and a Pico 2 board file | TinyUSB tree at 4da0a77, 2026-09-24 (verified) |
| Exposed GPIOs | 15: GPIO0–10 and GPIO26–29, plus 3V3/GND/VSYS. GPIO12/13 (PIO-USB) and GPIO16 (RGB LED) are not on the header, so nothing we use is contended | Schematic (verified) |
| BOOTSEL / reset | Key1 on QSPI_SS, Key2 on RUN. UF2 flashing unchanged | Schematic (verified) |
| Erratum RP2350-E9 | Input-mode pull-down latching, redefined as input-buffer leakage (up to ~120 µA), "fixed by documentation". **Doesn't apply to us:** every pin we use is driven and none relies on an internal pull-down | Sourced (Raspberry Pi forum, Hackaday); datasheet not read directly. Confirm at bring-up |

### Accepted costs

- **Two extra diodes.** The owner has them and is comfortable fitting them.
- **A second USB-C port on each input board, facing into the case.** It sits on the same `VSYS` net, on the host side of our diode, so anything plugged into it lands on that board's VBUS. The owner accepts leaving it unused and unreachable inside the enclosure.
- **2 MB flash instead of 8 MB.**
- **The enclosure coupon needs re-measuring**: 33.0 × 17.5 mm (sourced) against the QT Py's 20.7 × 17.8 mm. The *mounting method* does not change: the QT Py had no mounting holes either (verified from Adafruit's board file), so input boards were always held by the USB-C wall and cradle. Only the cradle dimensions move.

### What did not change

Same ESP32 chip, so A2DP/SBC, the 44.1 kHz constraint (#16), the one-clock-domain rule and the whole control-path design stand. The I2S pin numbers on the input board are unchanged (GP26/27/28/29); only the UART moves, from GP20/GP5 to GP4/GP5, which are a real UART1 pair.

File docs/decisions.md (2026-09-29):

# Decision log

Decisions made by the owner. Newest first. Reasoning and alternatives live in the linked docs.

| Date | Decision | Why | Details |
|---|---|---|---|
| 2026-09-29 | **Input boards: 2× Waveshare RP2350-USB-C**, each with an owner-supplied Schottky from its `VSYS` pin to the shared rail. Replaces the Adafruit QT Py RP2040. | 520 KB RAM vs 264 KB, which directly attacks the highest firmware risk (USB audio + lwIP + web server on one chip). The missing VBUS diode is no obstacle: the owner has diodes and is comfortable fitting them. | `hardware/wiring.md`, review-notes #20. Costs: 2 MB flash instead of 8 MB; a second USB-C port faces into the case (accepted, left unused); enclosure needs re-measuring. |
| 2026-09-29 | **ESP32 board: Waveshare ESP32-DEV-KIT-WROOM-32E-N4**, powered from the rail into its `VSYS` pin. Replaces the Adafruit ESP32 Feather V2. | The Feather has no supported way to take a non-battery supply: Adafruit warns that external supplies on `BAT` destroy the LiPoly charger (#19). This board's `VSYS` is a proper system-power input, its converter accepts 2.3–5.5 V, and onboard D3 protects its USB-C so the ESP32 can be flashed with the box powered. | `hardware/wiring.md`, review-notes #20. Same ESP32 chip, so A2DP/SBC and the 44.1 kHz constraint are unchanged. Pin map redone around GPIO27 (RGB LED) and GPIO34 (battery ADC). |
| 2026-09-28 | **Control channel: USB network adapter + web page served by the QT Py itself** (CDC-NCM/ECM, lwIP, HTTP/WebSocket). Commands relay to the ESP32 over UART; the ESP32 holds all state. | Fully self-contained: no internet, no other server, any browser (Safari included), no permission prompts. Hosting the page elsewhere was rejected as not simple. | `docs/architecture.md` §3. Fallback if the sound card + network device misbehaves on a host: USB MIDI or USB serial, with the same UART protocol. |
| 2026-09-28 | **The ESP32 does the mixing and is the audio clock master.** Both RP2040s become identical I2S slaves (receive the ESP32's clocks, send their USB audio). | Every adjustable mix setting then lives on the chip that receives the management commands. | `hardware/wiring.md`. Two direct inputs (the ESP32's two I2S peripherals); more inputs chain into an RP2040's DIN. |
| 2026-09-28 | **No buttons on the case.** Bluetooth pairing (scan, connect, forget) is done only through the USB control channel from any connected device's browser. | The owner always has some device with a browser to plug in. A firmware bug in the control path is fixed by reflashing (RP2040s over USB; ESP32 via its internal USB-C or later OTA). | Condition: the controlling device must plug into one of the box's USB-C ports (until/unless Wi-Fi control is added). With the self-served page, any browser works (see the control-channel entry). |
| 2026-09-28 | **Box is managed through a USB control channel** on the RP2040 input boards, relayed to the ESP32 over UART. No custom native app; a web page. | Driver-free, works from any connected host, doesn't use the Bluetooth radio. | Channel chosen: see the control-channel entry above. Wi-Fi web page on the ESP32 remains a possible later addition (station mode is rated stable alongside Classic Bluetooth by Espressif). |
| 2026-09-28 | **Bluetooth output: original ESP32** (candidate board: Adafruit ESP32 Feather V2) running an A2DP source, instead of the TSA5001. | Owner prefers it for the learning value and the control it gives (pairing, headphone volume, status, codec parameters). | SBC only. The owner accepts the added firmware work (pairing, reconnection, AVRCP volume). The TSA5001 stays as a fallback. See `viability-review.md` §3b. |
| 2026-09-24 | **Inputs: 2× RP2040.** XMOS and analog-mix alternatives rejected. | XMOS is too expensive; an analog mix adds a digital→analog→digital conversion. | `viability-review.md` §3a |
| ~~2026-09-24~~ | ~~**Board: Adafruit QT Py RP2040**~~ | Superseded 2026-09-29 by the RP2350-USB-C (see the top entry). | `hardware/board-comparison.md` |
| 2026-09-24 | **USB-C ports exposed directly through the enclosure wall.** No extension cables. | Fewer connectors; extensions only make things worse. | `enclosure/` |

## Open questions that follow from these decisions

| Question | Options | Notes |
|---|---|---|
| ~~Where does mixing happen?~~ | Resolved: ESP32 hub | See the 2026-09-28 entry |
| ~~Which USB control channel?~~ | Resolved: USB network + self-served page | See the control-channel entry |
| ~~Feather V2 power path~~ | Moot: the Feather is no longer the board | Superseded 2026-09-29. The analysis stays in review-notes #14, #17, #19 |
| ~~Feather charger chip (U3)~~ | Moot: board changed rather than modified | The owner chose a board designed for rail power instead of any of options A–D |
| ~~ESP32-A2DP library features~~ | Resolved: reconnect yes; volume yes with `A2DPNoVolumeControl` + passthrough handler | review-notes #16 (verified from source) |
| ~~Sample rate~~ | Not a choice: **44.1 kHz end to end is a constraint** | Stock ESP-IDF's A2DP source offers 44.1 kHz only (verified), and the design has one clock and no resampling. review-notes #16 |

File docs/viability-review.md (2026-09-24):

# Viability review

Written 2026-09-24, revised the same day. This judges the **outcome**, not the handoff's design.

## Scope (set by owner)

| | Target |
|---|---|
| **Inputs** | Any USB-C host that plays audio to a class-compliant USB audio device (UAC). No specific host is targeted. |
| **Output** | Any Bluetooth audio sink. No specific headphones are targeted. |
| **Power** | USB power from whichever input cables are connected. |
| **Use** | Game audio mixed with background music or video. No calls. The eyes stay on the game, so video lip sync is a minor concern. **Game-audio latency is the priority.** |

**Evidence labels:**

- **Verified:** checked against source code or a schematic.
- **Sourced:** from manufacturer or third-party text.
- **Estimate:** my judgment.

---

## 1. Verdict

| Question | Answer | Confidence |
|---|---|---|
| Can the outcome be built? | **Yes.** | ~85% that at least one path below works |
| Is the input side (2× QT Py RP2040, shared I2S clock) sound? | Yes | ~70% |
| What limits latency? | Mostly the Bluetooth transport and codec that the box and the sink can agree on, plus the sink's own buffer. **The box's microcontroller path is ~2–3 ms.** | See section 2 |

---

## 2. Where latency comes from

End-to-end path:

**host audio stack → USB (UAC2) → box → Bluetooth transmitter → radio link → sink decoder and buffer**

| Stage | Delay | Can the box change it? | Evidence |
|---|---|---|---|
| Host audio stack and USB buffering | Unknown; varies by host OS | No | — |
| TinyUSB FIFO in each board | ~2 ms average (held at half full) | Already near minimal | Verified: TinyUSB source comment |
| I2S hop, board B → board A | 1 frame ≈ 21 µs | No need | Calculated |
| Transmitter: input buffer, encoder, link settings | Depends on the transmitter | **Yes, by choosing the output stage** | — |
| Codec / transport negotiated with the sink | Largest single variable | **Partly.** The box can only offer codecs; the sink must support the same one. | — |
| Sink's own jitter buffer | Often the largest part | **No.** It's set by the sink's firmware. | Estimate |

**Consequences:**

- **The box's firmware and processors aren't a latency lever.** The only lever the box controls is the **output stage**: which transports and codecs it offers, and whether it prefers the lowest-latency one.
- **Ceiling:** a sink that supports only SBC over A2DP sets its own latency. No transmitter design fixes that.
- **Lip sync:** hosts won't shift video to compensate, because they see a USB sound card, not Bluetooth. Minor for this use case.

### 2a. Low-latency Bluetooth options a transmitter can offer

| Transport / codec | Sinks that support it | Latency notes | Evidence |
|---|---|---|---|
| A2DP SBC | All A2DP sinks (mandatory) | The baseline. The sink buffer dominates. | Sourced (A2DP spec: SBC is mandatory) |
| A2DP AAC | Many | Often no better than SBC, possibly worse | Estimate, medium confidence |
| A2DP aptX Low Latency | A smaller, older set of sinks | Designed for low latency | Sourced (Qualcomm marketing); no measurement |
| A2DP aptX Adaptive (low-latency mode) | Snapdragon Sound sinks | Creative claims ~50 ms for its BT-W5 dongle in this mode | Sourced (Creative) |
| LE Audio LC3 | Newer BT 5.2+ sinks | Designed for lower latency. Interoperability between vendors is still immature. | Sourced (Nordic docs, forum reports) |

**Best generic strategy:** offer as many of these as possible, and prefer the lowest-latency one each sink supports, with SBC as the fallback.

---

## 3. Architecture options

### 3a. Input stage: two USB device ports

| Option | Difficulty | Confidence | Notes |
|---|---|---|---|
| **2× RP2040 (QT Py), shared I2S clock** | 5–6/10 | ~70% | One board generates the only audio clock, so no sample-rate conversion is needed. The riskiest code is the second board's PIO I2S slave. |
| One chip with two USB device controllers | 7–8/10 | ~40% | **TinyUSB's device stack supports one port only** (verified: a single global `_usbd_rhport` in `usbd.c`). |
| RP2040 native USB + PIO-USB as the second device | 8/10 | ~25% | PIO-USB device mode is experimental; isochronous support is unknown. |

| **2× hardware USB-audio bridge chips (e.g., TI PCM2706: UAC1, I2S out), analog mix** | 3/10 | ~70% | **No firmware.** Each chip locks its sample clock to its own host, so the two outputs are in **different clock domains**. Mixing them in analog (each chip's DAC → resistor mix) sidesteps that. Output then needs an analog-input transmitter, or an ADC → I2S → TSA5001. Adds an analog stage, so hum/noise can enter from the hosts' tied grounds and USB power. UAC1 works on more hosts than UAC2. |
| 2× hardware bridge chips, digital mix | 6/10 | ~50% | Same clock-domain split, so it needs hardware ASRC chips plus a mixer MCU. More parts than the RP2040 route for no gain. |
| 2× XMOS (XU316) running XMOS's reference USB-audio firmware; one acts as I2S slave, the other uses the firmware's built-in mixer | 6–7/10 | ~45% | Mature, widely deployed USB-audio firmware. Heavy toolchain. **Power draw is likely much higher than RP2040** (estimate, unverified), which risks the one-host-powers-everything budget. |
| One STM32 with two USB device controllers (OTG_FS + OTG_HS in FS mode), ST's USB device library | 7/10 | ~45% | One chip, one clock domain, easy mixing. TinyUSB can't do two device ports (verified); ST's library can run two device instances, but I believe ST ships only a UAC1 class with no feedback (estimate), so UAC2 async would have to be written. Few boards expose both ports. |

**Decision (owner, 2026-09-24): 2× RP2040 (QT Py).** XMOS was rejected on cost, and the analog-mix route was rejected because it adds a digital→analog→digital conversion.

Previous recommendation, kept for the record: 2× QT Py. The firmware-free analog route is the credible alternative: it trades the firmware risk (PIO I2S slave, feedback loop) for analog noise risk and fewer output-stage options.

### 3b. Output stage (the latency lever)

| Option | What it offers | Difficulty | Confidence | Main risks |
|---|---|---|---|---|
| **A. TinySine TSA5001** (I2S in) | SBC, AAC, aptX, aptX HD, **aptX LL**. That list is the vendor's, relayed through the handoff; I haven't checked it myself. | 4/10 | ~60% | The codec is picked automatically with unknown priority; it might pick aptX HD over LL. Closed firmware. Minimum voltage and I2S format unknown. 48 kHz only (sourced). |
| **B. USB Bluetooth transmitter dongle** with aptX Adaptive low-latency mode (e.g., Creative BT-W5), fed by a **third RP2040 acting as USB audio host** | SBC, AAC, aptX Adaptive with a user-selectable low-latency priority (sourced, Creative). LE Audio support: not verified. | 7/10 | ~40% | **TinyUSB has a USB audio host driver** (verified) that supports playback and explicit feedback, and its example lists RP2040 as a build target (verified). I haven't verified that it runs reliably on RP2040. **Clock-domain problem:** if the dongle paces its own rate, board A's I2S clock must be trimmed to follow it, using board C's buffer level as a software PLL. That's extra work. |
| **C. LE Audio source**: nRF5340 running Nordic's unicast client app, I2S in | LE Audio LC3 only | 8/10 | ~30% | Only LE Audio sinks. Interop reports are mixed: works with Sony Inzone Buds; no audio with WF-1000XM6 or EarFun Air Pro 4. Adding a Classic transmitter as fallback raises this to 9/10. |
| **D. ESP32 + ESP32-A2DP** | SBC only, open and tunable | 6/10 | ~60% | Doesn't raise the ceiling. Only useful if buffer tuning helps, which is unmeasured. |
| **E. I2S DAC → analog Bluetooth transmitter** | Whatever that transmitter offers | 3/10 | ~75% | An extra digital→analog→digital conversion. Mostly a fallback for reliability, not latency. |

**Recommendation (not a decision):**

1. **Build with option A first.** It's cheap and already offers aptX LL. On the first test with a sink that supports several codecs, find out which codec the TSA5001 actually picks.
2. **If lower latency is needed on more sinks, option B is the next step.** aptX Adaptive's low-latency mode is the most widely deployed low-latency Classic option I can source. It costs a third board and the clock-trim work.
3. **Option C only if LE Audio sinks become the priority.** It has the highest potential and the highest interop risk.

The board A I2S output stays the same for A, C, D and E. Option B adds board C, which receives board A's I2S.

### 3c. Paths that don't build this box

| Option | Difficulty | Confidence | Meets outcome? |
|---|---|---|---|
| 2 USB-C DAC dongles → resistor mix → Bluetooth transmitter | 2/10 | ~80% | Partly. The transmitter needs its own power. Ground-loop hum risk. |
| Stream one host's audio to the other over a network; that host pairs to the sink directly | 1–2/10 | Depends on host | Partly. Needs software on both hosts. |

---

## 4. Risk list for the recommended path (ranked)

| # | Risk | Impact | How to retire it |
|---|---|---|---|
| 1 | Bluetooth latency too high for gaming with a given sink | Depends on the sink; see section 2 ceiling | Measure the built box (handoff milestone 7 method). Direct pairing to a host is only a rough proxy. |
| 2 | TSA5001: voltage, I2S format, codec priority | Output-stage swap | One QT Py sending a test tone → TSA5001, before any USB work |
| 3 | PIO I2S slave on board B | Mixing | Logic analyzer; existing community code |
| 4 | USB feedback (clock matching) misbehaves on a host | Clicks or dropouts | Buffer-level logging over UART (development only) |
| 5 | USB-C wall mount stresses the solder joints | Board failure over time | Print the wall and cradle first |

---

## 5. Recommended order (risk first)

1. **Output stage, one board.** A QT Py as I2S master sends a generated sine wave → TSA5001 → a sink. No USB yet. Record the voltage, the I2S format, and the codec picked for each sink you try.
2. **USB input, one board.** The QT Py enumerates as a UAC2 speaker and plays through the TSA5001.
3. **Second board.** PIO I2S slave, mixing on board A.
4. **Shared power and hot-plug.**
5. **Latency measurement** per sink and codec.
6. **Enclosure.** Wall-and-cradle test print first; this can run in parallel from step 1.
7. **Only if needed:** output-stage upgrade (3b, option B or C).

---

## Sources

- TinyUSB source (cloned 2026-09-24): https://github.com/hathach/tinyusb (`src/class/audio/audio_host.*`, `examples/host/audio_host`)
- TSA5001 48 kHz-only note: https://github.com/pschatzmann/arduino-audio-tools/discussions/1433
- TSA5001 product page: https://www.tinysineaudio.com/products/tsa5001-bluetooth-5-3-audio-transmitter-board-i2s-digital-input
- Creative BT-W5 (aptX Adaptive low-latency mode, ~50 ms claim): https://us.creative.com/p/accessories/creative-bt-w5
- nRF5340 Audio unicast client (I2S/USB input): https://nrfconnectdocs.nordicsemi.com/ncs/2.6.1/nrf/applications/nrf5340_audio/unicast_client/README.html
- LE Audio interop reports: https://devzone.nordicsemi.com/f/nordic-q-a/124106/nrf5340-nora-b126-as-hci-controller-for-le-audio-on-raspberry-pi-cm4-pairs-ok-no-audio-with-sony-wf-1000xm6 and https://github.com/zephyrproject-rtos/zephyr/discussions/96481
- TI PCM2706 (UAC1, I2S mode via FSEL): https://www.ti.com/product/PCM2706
- Board schematics: see `hardware/board-comparison.md`

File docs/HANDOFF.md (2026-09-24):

# Project Handoff: 2-Input USB-C → Bluetooth Audio Mixer

This file summarizes a planning conversation, so work can continue in Claude Code.
Tip: drop it into the repo root. Rename it to `CLAUDE.md` if you want Claude Code to load it automatically.

---

## 1. Working preferences (please follow)

- **Owner assesses risk and tradeoffs.** Give accurate information and honest feasibility reads, including for hard or dead-end paths. Don't steer toward easier alternatives or soften difficulty.
- **Rate difficulty (x/10) and confidence (%) explicitly.** State recommendations as recommendations, never as decisions. Keep uncertainty visible, and mark what's verified vs. assumed.
- **Readability:** the owner has ADHD and is dyslexic. Use short paragraphs, clear headings, tables, and small verifiable steps.
- **Red/green color blind:** never use red vs. green alone to convey meaning. That applies to UI, plots, logic-analyzer annotations, and LED status schemes; use shape, text, position, or blue/orange instead.
- **Fabrication:** the enclosure will be 3D printed (Elegoo Centauri Carbon). Avoid carbon-fiber-filled filament near the antenna, because it attenuates 2.4 GHz.

---

## 2. Goal

A small box with **two USB-C inputs** and **one Bluetooth audio output**:

- Each USB-C port connects to a computer, or a phone that supports USB audio. That device sees the box as a normal USB sound card (UAC2, class compliant, no drivers).
- The box **mixes both inputs** and streams the mix to Bluetooth headphones.
- The box is **powered by whichever USB-C cable(s) are connected**.

No commercial single-box product doing this was found, so it's a custom build.

### How we got here (rejected or deferred options)

| Option | Status | Why |
|---|---|---|
| Multiple Bluetooth *inputs* mixed on a Pi Zero 2 W / Linux (PipeWire) | Dropped | The requirements changed. The radio needs multiple roles at once (scatternet), which is flaky; latency is two Bluetooth hops. |
| Raspberry Pi (any model) as the dual USB device | Rejected | Every Pi has at most one USB device-capable port. |
| Off-the-shelf chain: 2 USB-C DAC dongles → resistor mix → commercial BT transmitter | Viable but not chosen | Difficulty 2/10, ~85% confidence. Risk of ground-loop hum. The owner wants a custom single box. |
| 2× RP2040 + ESP32 (A2DP source, SBC only) | **Fallback** | ESP32 = original ESP32 only (WROOM-32 / PICO-MINI-02); S2/S3/C-series lack Classic BT. |
| STM32 with two USB device controllers | Deferred | Elegant clocking, but dual-port UAC2 under TinyUSB is little-tested. |
| nRF5340 LE Audio (LC3) output stage | Future experiment | Only relevant for LE Audio headphones such as the Sony XM5. Difficulty 8–9/10, ~30% confidence (interoperability risk). |
| **2× Pico + TinySine TSA5001 (I2S → Bluetooth)** | **Current plan** | See below. |

---

## 3. Current architecture

```
Computer A ──USB-C──► Pico A (UAC2 device + I2S MASTER + mixer + limiter) ──I2S──► TSA5001 ──BT──► headphones
                         ▲
                         │ I2S data (clocked by Pico A)
Computer B ──USB-C──► Pico B (UAC2 device + I2S SLAVE)
```

- **Pico A generates the only audio clock** (bit clock and word select) at **48 kHz**. It drives Pico B and the TSA5001.
- **Pico B** receives the clock and sends its audio to Pico A. Its "upstream" data input is tied to GND (the start of the chain).
- **Pico A** computes `out = limiter(own_sample + picoB_sample)` and sends the result to the TSA5001.
- **Both computers sync to Pico A's clock** through UAC2 asynchronous feedback (see 5.1). The result is no sample-rate conversion and no drift handling in the Picos.
- **The TSA5001** (Qualcomm-based) is an I2S slave. It picks the Bluetooth codec automatically and handles its own Bluetooth timing.
- **Design for swappability:** keep a firmware setting for the I2S role, so the output stage can be swapped for an ESP32 or nRF5340 without rewiring upstream.

### Chain design notes
- Carry **32-bit I2S slots** between the Picos (16-bit USB samples sign-extended), so sums never clip mid-chain.
- Only the **last stage (Pico A)** scales and limits down to the TSA5001's output format.
- One firmware image with a config flag: `ROLE_MASTER_LAST` (Pico A) or `ROLE_SLAVE` (Pico B). This scales to more inputs by chaining more slave Picos.

---

## 4. Hardware

### Bill of materials

| Part | Qty | Notes | Approx. cost |
|---|---|---|---|
| Raspberry Pi **Pico or Pico 2 (NOT the W versions)** | 2 | On W boards, USB power sense isn't on GPIO24 (it goes through the wireless chip). | ~$4–5 each |
| TinySine **TSA5001**, BT 5.3 I2S transmitter | 1 (buy 2) | I2S slave, 48 kHz, 16/24/32-bit, aptX / aptX LL / aptX HD / SBC / AAC, A2DP only. $14.95 from tinysineaudio.com. The sibling TSA5002 is the same on paper but out of stock. | $14.95 |
| 2.4 GHz antenna, U.FL (IPEX / MHF1) | 1 | Flat adhesive to start; U.FL-to-SMA bulkhead if you see dropouts. **Confirm the connector type** from the board. | ~$3–8 |
| Panel-mount USB-C (female) → micro-USB (male) extension, **data-capable** | 2 | The Picos are micro-USB. | ~$3–6 each |
| Momentary normally-open pushbutton (panel-mount, 6–12 mm) | 1 | The TSA5001's pairing control is a **header**, not a button. Hold 3 s = search; 5 s = clear pairing. Consider recessing it. | ~$1–3 |
| Capacitor, 22–47 µF, ≥10 V | 1 | Across the rail near the TSA5001. Stay ≤ ~47 µF because of USB's limit on capacitance at plug-in. | <$1 |
| 33 Ω resistors | 4 | In series on the bit clock and word select lines leaving Pico A (to Pico B and to the TSA5001). | <$1 |
| 26–28 AWG hookup wire, M2 screws/standoffs | — | | ~$8 |
| 3D-printed enclosure | 1 | Access to the pairing switch, a window or light pipe for the TSA5001 LED, antenna at the edge facing the user. | — |

**Tools:** soldering iron, multimeter, micro-USB data cable, **a cheap 8-channel 24 MHz logic analyzer with PulseView (close to essential)**.
**Optional:** a PCM5102A I2S DAC board, to *hear* Pico A's I2S output before the TSA5001 arrives or to rule out Bluetooth problems.

Estimated total: ~$40–55 plus shipping.

### Power design (confidence ~85%)
- Each Pico has an onboard Schottky diode from **VBUS to VSYS**. **Tie Pico A VSYS to Pico B VSYS.** The two diodes then combine both USB supplies, and the computers are never connected to each other.
- **NEVER connect the two VBUS pins together.**
- The TSA5001 power input goes to the shared VSYS rail. The rail is **~4.6–4.8 V**, not 5 V. **Open question:** does the TSA5001 run reliably at that voltage? About 75% likely. Test it, or ask TinySine for the minimum input voltage.
- Both Picos are always powered together. That prevents an unpowered RP2040 from being powered through its I/O pins by Pico A's clock signals.
- Each Pico reads **its own** VBUS on **GPIO24** (USB side, before the diode) to know whether its computer is connected.
- Budget: Picos ~20–30 mA each, TSA5001 ~30–60 mA while streaming (estimate; the listed "6 mA" is surely idle). Total ~70–120 mA. Declare ~200 mA `bMaxPower` in **both** Picos' descriptors.
- Connecting the two computers' grounds through the box is acceptable because the audio path is all digital.

### Wiring

Pin numbers are **suggestions**; adjust for PIO pin-group constraints.

| Signal | From | To | Suggested GPIO |
|---|---|---|---|
| Bit clock (BCLK), 3.072 MHz | Pico A (via 33 Ω) | Pico B, and the TSA5001 via its own 33 Ω | A: GP10 → B: GP10 |
| Word select (LRCK), 48 kHz | Pico A (via 33 Ω) | Pico B, and the TSA5001 via its own 33 Ω | A: GP11 → B: GP11 |
| Data | Pico B DOUT | Pico A DIN | B: GP12 → A: GP13 |
| Data | Pico A DOUT | TSA5001 SD | A: GP12 |
| Chain start | Pico B DIN | GND | B: GP13 |
| Rail | Pico A VSYS | Pico B VSYS, TSA5001 +, capacitor | — |
| Ground | all | all | — |
| Pairing | pushbutton | across the TSA5001 pairing header | — |

The TSA5001 I2S header has SD, LRCK, BCLK, MCLK (unused), and GND. Keep the I2S wires under ~10 cm.

Optional: let Pico A trigger pairing through an NPN transistor or N-MOSFET across the pairing header. Only drive the header directly from a GPIO if you've measured it at ≤3.3 V.

---

## 5. Firmware (Pico SDK + TinyUSB, C)

### 5.1 USB side (both Picos)
- TinyUSB **UAC2 speaker**: 48 kHz, 16-bit, stereo, **asynchronous mode with a feedback endpoint**.
- **Base the feedback on how full the audio buffer is.** Each Pico's buffer drains at Pico A's I2S clock rate, not the Pico's own USB timing. TinyUSB has a feedback method based on buffer count and a `uac2_speaker_fb` example. **Verify the current API names; they've changed across versions.**
- Give each Pico distinct USB product strings and serial numbers (e.g., "BT Mixer Input A" / "BT Mixer Input B").
- Volume: likely omit the volume control from the descriptor, so the OS applies software volume and each computer's slider sets its level in the mix. Medium confidence; verify on macOS and Windows.
- Test on macOS/Linux first. Windows' built-in UAC2 driver (Win10 1703+) is stricter about descriptors and the feedback format.

### 5.2 I2S (PIO)
- Standard I2S (Philips) framing, 2 × 32-bit slots per frame, BCLK = 64 × 48 kHz = 3.072 MHz.
- **Pico A:** PIO I2S **master** transmitter (to the TSA5001) plus a receiver for Pico B's data, using its own clock. This is the well-trodden case.
- **Pico B:** PIO I2S **slave** that follows the external BCLK/LRCK: transmit, plus receive upstream data for chain scalability. **This is the riskiest custom code.** Expect ~20–30 PIO instructions and time with a logic analyzer.
- **Clock accuracy:** choose a system clock that divides evenly into the I2S clock. For example, 153.6 MHz (12 MHz × 128 → VCO 1536 MHz, divided by 5 and 2) = 50 × 3.072 MHz. That avoids fractional-divider jitter. USB keeps its separate 48 MHz PLL.
- **Open question:** the exact I2S format the TSA5001 expects (Philips vs. left-justified, slot width, bit alignment). Confirm with the logic analyzer and trial.

### 5.3 Per-sample logic
- `sum = upstream_in (int32) + own_usb_sample (sign-extended to 32-bit)`
- Slave role: send `sum` downstream in a 32-bit slot.
- Master/last role: apply a soft limiter, then output 16- or 24-bit (left-aligned in a 32-bit slot, per the TSA5001's format).
- USB buffer empty → contribute zeros. No computer connected (GPIO24 low) → contribute zeros but **still pass upstream audio through**.

---

## 6. Build milestones (each works on its own before the next)

| # | Step | Difficulty |
|---|---|---|
| 1 | Pico A enumerates as a UAC2 speaker on Mac/PC; log the buffer fill level over serial. | 3/10 |
| 2 | Pico A as I2S master → PCM5102A DAC (optional): hear the audio, confirm the buffer level stays steady (feedback working). | 4/10 |
| 3 | Power the TSA5001 from the VSYS rail (check the voltage first); feed it Pico A's I2S; pair headphones; confirm the format and streaming. | 4/10 |
| 4 | Pico B slave transmit, verified on the logic analyzer; mix at Pico A. **Riskiest step.** | 6/10 |
| 5 | Shared power: hot-plug each cable while audio plays, and check the silence behavior. | 3/10 |
| 6 | Enclosure, antenna, pairing switch, panel USB-C jacks. | — |
| 7 | Latency measurement for each headphone model (method below). | 2/10 |

**Overall: difficulty ~5/10, confidence ~65–70%.**

**Latency measurement:** play a sharp click from the computer through the box. Record with a phone microphone near the earbud, with a wired speaker on the computer playing the same click. The gap between the two clicks is the added latency.

---

## 7. Headphones and latency

The TSA5001 picks the codec automatically. Qualcomm transmitters usually choose the "best" codec both ends support, which likely means **AAC where available. AAC usually has *more* latency than SBC** (medium confidence). The codec can't be forced or tuned (closed firmware).

| Headphones | Codecs | Notes | Expected total latency |
|---|---|---|---|
| Shokz OpenMove | SBC only | No known low-latency mode. | ~150–250 ms |
| Nothing Ear (open) | SBC, AAC | **Low Lag Mode** (Nothing X app, claimed <120 ms with a phone). Other Nothing/CMF models reportedly **reset it on reconnect**; ~40–50% it persists. Workaround: keep the phone connected via multipoint and toggle it per session. The box can't send the command (closed TSA5001 firmware). | ~110–170 ms with Low Lag, ~150–250 ms without (low-to-medium confidence) |
| Sony WF-1000XM5 | SBC, AAC, LDAC, LC3 (LE Audio) | Sony's "Low latency" mode *is* LE Audio. The TSA5001 is A2DP only, so no benefit; AAC via the TSA5001. LE Audio would need a future nRF5340 stage. | ~150–250+ ms |

Latency sources: USB ~5–10 ms, Pico buffers ~2–5 ms, the remainder is the Bluetooth link and the headphones' buffer (the dominant, uncontrollable part). A faster processor would **not** help meaningfully; only codec and buffering choices matter.

---

## 8. Open questions and risks

| Item | Status | Confidence |
|---|---|---|
| Pico B's PIO I2S slave program | Custom code; the main risk | — |
| TSA5001 works at ~4.6–4.8 V | Test, or ask TinySine | ~75% |
| TSA5001's I2S format / slot width | Confirm by trial | — |
| TSA5001 antenna connector = U.FL | Check the board | High, not verified |
| TSA5001 LED on a header? | Check on arrival | Unknown |
| TinyUSB feedback API names and behavior | Verify against the current release | Medium-high |
| Windows UAC2 feedback quirks | Test | Medium |
| TSA5001 codec choice (AAC vs. SBC) and latency | Measure | Medium |
| Nothing Low Lag persistence with the box | Test at milestone 3 | ~40–50% |

## 9. Fallback: ESP32 output stage
If the TSA5001 disappoints, use an **original ESP32** (e.g., Adafruit ESP32 Feather V2 / ESP32-PICO-MINI-02, or DevKitC with WROOM-32E) running Phil Schatzmann's **ESP32-A2DP** `BluetoothA2DPSource` (SBC only).

- Either the ESP32 becomes the I2S master (the original plan: I2S0 master receive using the audio PLL, a ring buffer, and a slip handler), or it runs as a slave to Pico A.
- Power it from the rail through a low-dropout 3.3 V regulator (e.g., AP2112K) into its 3V3 pin.
- Upside: sender queue tuning is possible, and the Nothing Low Lag command could in theory be sent over RFCOMM (reverse-engineered protocol, ~40% confidence, GPL-3.0 reference project `nothingx-pc`).

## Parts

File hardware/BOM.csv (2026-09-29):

item | qty | part | notes | approx_cost_usd | status
1 | 2 | Waveshare RP2350-USB-C | USB audio inputs. RP2350A; 520 KB RAM; 2 MB flash (W25Q16); 33.0 x 17.5 mm; USB-C at BOTH ends. NO onboard VBUS diode - VSYS is raw VBUS and both ports share it - so item 3 is mandatory. CC 5.1k present on both ports. Schematic-verified. Replaces QT Py RP2040 (review-notes #20) | TBD | to buy
2 | 1 | Waveshare ESP32-DEV-KIT-WROOM-32E-N4 (original ESP32; Classic BT for A2DP source) | Chosen BT output (docs/decisions.md). Power: shared rail -> VSYS pin (J3-19); onboard D3 protects its own USB-C so it can be flashed with the box powered. MP1605 converter 2.3-5.5 V in. Never fit a battery to the GH1.25 connector. Onboard antenna: place near a non-CF wall. Replaces Feather V2 (review-notes #20) | TBD | to buy
3 | 2 | Schottky diode (1N5817 / SS14 or similar; low Vf; >=1 A) | One per input board: board VSYS -> shared rail; cathode (banded end) to the rail. REQUIRED because the RP2350-USB-C has no onboard VBUS diode. Owner already has suitable parts | <1 | have
4 | 4 | Resistor 33 ohm | Series on BCLK and LRCK at the clock master's pins (one per receiving board) | <1 | to buy
5 | 1 | Capacitor 22 uF >=10 V | Bulk on rail near the ESP32 (BT transmit current bursts); start 22 uF (review-notes #3) | <1 | to buy
6 | 3 | Capacitor 0.1 uF ceramic | Local decoupling at ESP32 power input and rail junction | <1 | to buy
7 | 1 | Perfboard / protoboard (small) | Holds diode + resistors + caps; single split point for clock and power lines | 1-3 | to buy
8 | 1 | Silicone hookup wire 26-28 AWG (several colours) | Board-to-board wiring; keep I2S runs < ~10 cm | 5-8 | to buy
9 | 1 | M2.5 screws + heat-set inserts (small kit) | Enclosure lid | and the ESP32 board if it has holes. The input boards are NOT screw-mounted: neither the QT Py (verified: no holes in Adafruit's board file) nor the RP2350-USB-C; both are held by the USB-C wall + cradle. The Feather V2 had two M2.5 holes; whether the Waveshare ESP32 dev kit does is UNVERIFIED | 5-10 | to buy
10 | 1 | Heat-shrink tubing assortment | Insulating wire joints | 3-5 | to buy
11 | 1 | 3D-printed enclosure | No CF-filled filament near the antenna. USB-C wall test coupon ready in enclosure/ but sized for the QT Py - re-measure for the RP2350-USB-C. Each input board has a second USB-C port facing inward: leave it unused and unreachable | - | to design
12 | 1 | Light pipe (optional) | Only if a visible status LED is wanted (not red/green-coded) | 1-3 | optional
T1 | 1 | 8-ch 24 MHz logic analyzer (PulseView) | Strongly recommended for I2S debugging | 10-15 | tool
T2 | 1 | Calipers | Measure input-board PCB thickness and USB shell height for the enclosure (board changed to RP2350-USB-C; re-measure) | 10-25 | tool
T3 | 1 | Soldering iron + solder + flux | Flux helps a lot on castellated pads | - | tool
T4 | 1 | Multimeter | Rail voltage; continuity; diode direction | - | tool
T5 | 2 | USB-C data cables | Hosts and flashing | - | tool
T6 | 1 | 3.3 V USB-serial adapter (CP2102 / CH340 / FT232) | Optional: input-board debug logs. GP4/GP5 UART1 goes to the ESP32 link; logs move to a PIO serial pin (GP3) | 3-8 | optional
T7 | 1 | PCM5102A I2S DAC board | Optional: hear the I2S mix before Bluetooth works (SCK jumper to GND) | 5-10 | optional
F1 | 2 | TinySine TSA5001 BT 5.3 I2S transmitter | Fallback BT output. I2S slave; 48 kHz; A2DP only. Sellers: tinysineaudio.com; tinyosshop.com; Oz Robotics; Audiophonics (EU); eltim.eu (EU) | 14.95 each (tinyosshop) | fallback (not buying now)
F2 | 1 | 2.4 GHz antenna U.FL (IPEX/MHF1) | TSA5001 fallback only | 3-8 | fallback (not buying now)

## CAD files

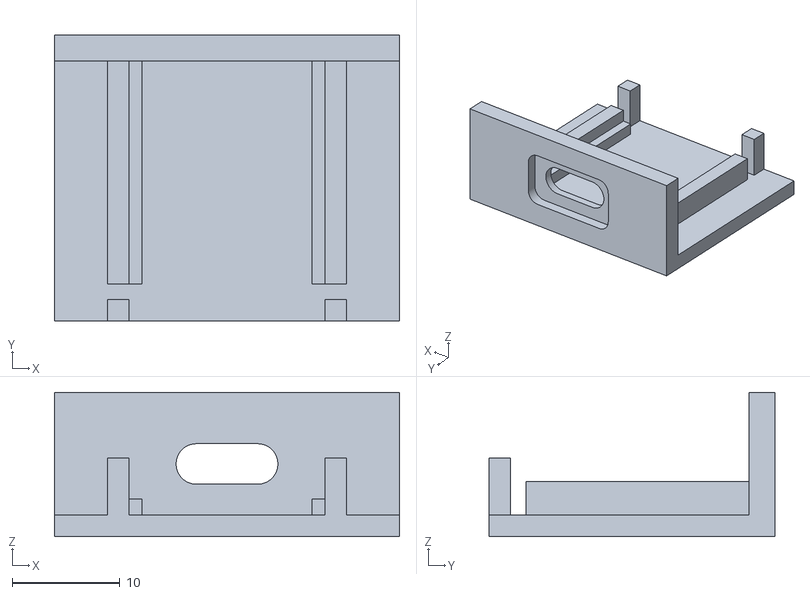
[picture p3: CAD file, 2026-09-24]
enclosure/stl/usb_wall_test_coupon.stl
32.0 x 26.5 x 13.4

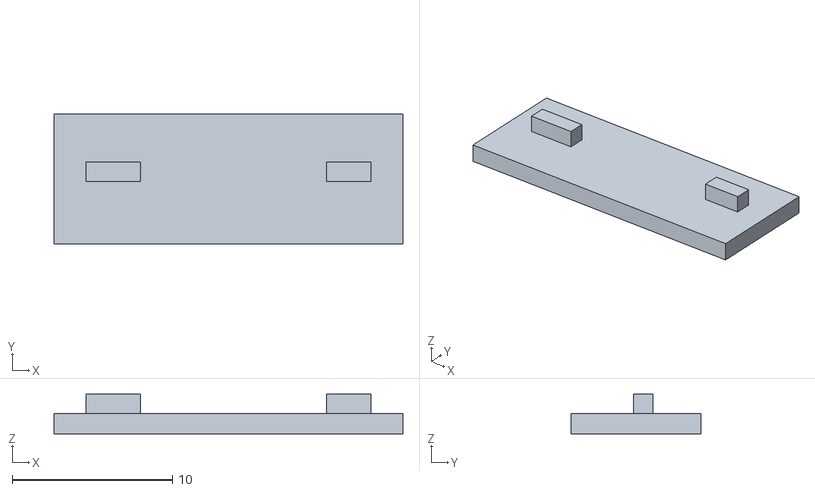
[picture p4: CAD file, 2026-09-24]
enclosure/stl/usb_wall_test_key.stl
21.8 x 8.10 x 2.48

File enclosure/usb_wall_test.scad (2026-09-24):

// USB-C wall + cradle test coupon for one Adafruit QT Py RP2040.
//
// Purpose: check port alignment, cable seating, and that plug forces go into
// the enclosure instead of the board's solder joints — before designing the
// full box.
//
// Parts:
//   coupon() — base, wall with USB-C opening, cradle for the board
//   key()    — drop-in clip behind the board: takes push-in force and holds
//              the back of the board down
//
// Assembly: lower the board into the cradle about 1.5 mm back from the wall,
// slide it forward so the USB-C shell enters the opening, then drop key()
// into the slots behind it.
//
// Coordinates (board frame, from Adafruit's Eagle .brd):
//   X = across the board, 0..17.78
//   Y = along the board, 0 = back edge, 20.70 = USB edge
//   Z = 0 at the board's bottom face
//
// Values marked MEASURE are not in the board file. Check them with calipers
// and edit before printing the final enclosure.

/* [Board — Adafruit QT Py RP2040] */
board_w = 17.78;   // from .brd outline
board_l = 20.70;   // from .brd outline
pcb_t   = 1.60;    // MEASURE: PCB thickness (assumed 1.6)

/* [USB-C receptacle] */
usb_w    = 8.94;   // shell width, from footprint outline
usb_h    = 3.26;   // MEASURE: shell height (typical top-mount value)
usb_over = 1.03;   // shell overhang past board edge, from footprint + placement
usb_cx   = 8.89;   // shell centre X, from placement

/* [Fit — tune with this print] */
fit       = 0.20;  // board-to-pocket clearance per side
hole_c    = 0.25;  // shell-to-opening clearance per side
key_fit   = 0.15;  // key blade play in its slot

/* [Wall] */
wall_t    = 2.4;
wall_w    = 32;
wall_top  = pcb_t + usb_h + 5;   // wall height above board bottom

/* [Cable overmold pocket, outer face] */
om_w = 13.0;       // pocket width  (fits most USB-C overmolds)
om_h = 7.2;        // pocket height
om_r = 1.5;        // pocket corner radius
mouth_recess = 0;  // pocket floor distance in front of receptacle mouth

/* [Cradle] */
under_clear = 1.5; // gap under board; tallest underside part ~1.1 (SOD-323)
base_t      = 2.0;
side_t      = 2.0;
ledge_w     = 1.0; // support ledges under the long edges (clear of underside parts)

/* [Key (back retainer)] */
install_margin = 0.4;                // extra room to lower the board past the shell overhang
key_t   = usb_over + install_margin; // slot width in Y
back_t  = 2.0;                       // material behind the slot
lip_t   = 1.2;                       // lip thickness over the board top
lip_len = 1.2;                       // lip reach over the board
grip_h  = 3.0;                       // key sticks up this far above the posts
// Lip only at the back corners: STEMMA QT connector spans X 4.0–10.1,
// reset button X 10.4–14.6 (from .brd).
lip_spans = [[0, 3.4], [15.0, board_w]];

/* [Hidden] */
$fn = 48;
eps = 0.01;

z_base_top = -under_clear;
z_base_bot = -under_clear - base_t;
x_in_l  = -fit;
x_in_r  = board_w + fit;
x_out_l = x_in_l - side_t;
x_out_r = x_in_r + side_t;
y_wall_in  = board_l;
y_wall_out = board_l + wall_t;
y_back     = -(key_t + back_t);
z_post_top = pcb_t + lip_t + 1.0;
usb_zc     = pcb_t + usb_h / 2;

module rrect(w, h, r, d) {
    // rounded rectangle in XZ, centred, extruded along +Y by d
    // hull of corner circles: stays valid when r = h/2 (stadium shape),
    // where offset() of a zero-height square would produce nothing
    rr = min(r, w / 2, h / 2);
    rotate([-90, 0, 0])
        linear_extrude(d)
            hull()
                for (sx = [-1, 1], sz = [-1, 1])
                    translate([sx * (w / 2 - rr), sz * (h / 2 - rr)]) circle(rr);
}

module wall() {
    difference() {
        translate([usb_cx - wall_w / 2, y_wall_in, z_base_bot])
            cube([wall_w, wall_t, wall_top - z_base_bot]);
        // shell opening, through
        translate([usb_cx, y_wall_in - eps, usb_zc])
            rrect(usb_w + 2 * hole_c, usb_h + 2 * hole_c, (usb_h + 2 * hole_c) / 2, wall_t + 2 * eps);
        // overmold pocket; floor sits mouth_recess in front of the receptacle mouth
        pocket_d = y_wall_out - (y_wall_in + usb_over + mouth_recess);
        if (pocket_d > 0)
            translate([usb_cx, y_wall_out - pocket_d, usb_zc])
                rrect(om_w, om_h, om_r, pocket_d + eps);
    }
}

module cradle() {
    difference() {
        union() {
            // base plate
            translate([min(x_out_l, usb_cx - wall_w / 2), y_back, z_base_bot])
                cube([max(x_out_r, usb_cx + wall_w / 2) - min(x_out_l, usb_cx - wall_w / 2),
                      y_wall_in - y_back + eps, base_t]);
            // side walls, flush with board top so castellated pads stay reachable
            for (x0 = [x_out_l, x_in_r])
                translate([x0, y_back, z_base_top - eps])
                    cube([side_t, y_wall_in - y_back + eps, pcb_t - z_base_top + eps]);
            // ledges under the long edges
            for (x0 = [x_in_l, board_w - ledge_w])
                translate([x0, 0, z_base_top - eps])
                    cube([ledge_w + fit, board_l, -z_base_top + eps]);
            // taller back posts that hold the key
            for (x0 = [x_out_l, x_in_r])
                translate([x0, y_back, z_base_top - eps])
                    cube([side_t, back_t + key_t, z_post_top - z_base_top + eps]);
        }
        // key slots through the back posts
        for (x0 = [x_out_l, x_in_r])
            translate([x0 - eps, -key_t, z_base_top])
                cube([side_t + 2 * eps, key_t, z_post_top - z_base_top + 1]);
    }
}

module coupon() {
    union() { wall(); cradle(); }
}

module key() {
    blade = key_t - key_fit;
    len   = (x_out_r - x_out_l) - 0.4;
    x0    = x_out_l + 0.2;
    union() {
        // blade: fills the gap behind the board edge, ends ride in the post slots
        translate([x0, -key_t + key_fit / 2, z_base_top + 0.2])
            cube([len, blade, z_post_top + grip_h - z_base_top - 0.2]);
        // corner lips over the board top
        for (s = lip_spans)
            translate([s[0], -key_t + key_fit / 2, pcb_t + 0.1])
                cube([s[1] - s[0], blade + lip_len, lip_t]);
    }
}

// Ghost board and shell, preview only (F5)
module board_ghost() {
    %color("SteelBlue", 0.5) cube([board_w, board_l, pcb_t]);
    %color("Silver", 0.6)
        translate([usb_cx, board_l + usb_over - 7.35, usb_zc])
            rrect(usb_w, usb_h, usb_h / 2, 7.35);
}

/* [Output] */
part = "preview"; // [preview, coupon, key]

if (part == "coupon") {
    // base on the bed
    translate([0, 0, -z_base_bot]) coupon();
} else if (part == "key") {
    // print lying on its back face, lips pointing up
    rotate([90, 0, 0]) translate([0, key_t - key_fit / 2, 0]) key();
} else {
    coupon();
    color("DarkOrange") key();
    board_ghost();
}

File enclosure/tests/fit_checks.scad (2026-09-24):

// Interference checks for usb_wall_test.scad. Run via tests/check_fit.sh.
// Board/shell numbers must match usb_wall_test.scad.
use <../usb_wall_test.scad>
which = 0;
pcb_t = 1.6; usb_w = 8.94; usb_h = 3.26; usb_over = 1.03; usb_cx = 8.89;
bw = 17.78; bl = 20.70;
module board_solid() { cube([bw, bl, pcb_t]); }
module shell_solid() { translate([usb_cx, bl + usb_over - 7.35, pcb_t + usb_h / 2]) rrect(usb_w, usb_h, usb_h / 2, 7.35); }
module stemma()      { translate([4.0, 0.30, pcb_t]) cube([6.1, 4.25, 2.5]); }  // from .brd
module board_install() { translate([0, -1.5, 0]) { board_solid(); shell_solid(); } }
// guards: must be non-empty
if (which == 10) shell_solid();
if (which == 11) coupon();
if (which == 12) key();
// collisions: must be empty (or zero-volume contact)
if (which == 1) intersection() { coupon(); board_solid(); }
if (which == 2) intersection() { coupon(); shell_solid(); }
if (which == 3) intersection() { coupon(); key(); }
if (which == 4) intersection() { key(); board_solid(); }
if (which == 5) intersection() { key(); stemma(); }
if (which == 6) intersection() { coupon(); board_install(); }

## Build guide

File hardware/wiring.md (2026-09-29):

# Wiring: ESP32 hub design

2× **Waveshare RP2350-USB-C** (USB audio inputs) → **Waveshare ESP32-DEV-KIT-WROOM-32E-N4** (clock master, mixer, Bluetooth A2DP source).

Replaces the earlier RP2040-chain pin map and `docs/HANDOFF.md` §4. Board decisions: `docs/decisions.md` (2026-09-29). The earlier QT Py RP2040 + Feather V2 pin map is superseded; see review-notes #20 for why the boards changed.

**Status:** proposed, not yet built. Pin numbers come from the boards' schematics, checked. Whether the I2S and UART setup works is untested.

```
                     BCLK, LRCK (ESP32 is clock master)
            ┌───────────────────────┬──────────────────────┐
            │                       │                      │
 Host 1 ─USB─▶ RP2350 1 ──DOUT──▶ ESP32 I2S0 (RX, master)   │
               UART ◀──────────▶ ESP32 UART1               │
                                                           │
 Host 2 ─USB─▶ RP2350 2 ──DOUT──▶ ESP32 I2S1 (RX, slave) ◀──┘ (BCLK/LRCK looped back)
               UART ◀──────────▶ ESP32 UART2

 ESP32: mix + gain + limiter → Bluetooth A2DP (SBC) → headphones
```

## Why the ESP32 uses two I2S peripherals

- The original ESP32 has **two I2S peripherals, each with one data input** in standard mode (TDM support on the original ESP32 is unlikely, ~75% confident).
- **I2S0** runs as **master**: it generates BCLK/LRCK and receives input 1.
- **I2S1** runs as **slave** on the same clocks and receives input 2.
- BCLK and LRCK are **wired back into two input-only pins** for I2S1. Routing them internally is probably possible too (~70% confident), but a physical loop-back wire removes that uncertainty for the cost of two otherwise-idle pins.

## ESP32 board pins (Waveshare ESP32-DEV-KIT-WROOM-32E-N4)

From Waveshare's schematic `ESP32-DEV-KIT-XX.pdf` (Altium, dated 2026-09-09). Header J3 is the left side, J4 the right.

| Signal | ESP32 GPIO | Header | Direction | Notes |
|---|---|---|---|---|
| BCLK out (I2S0 master) | 25 | J3 | Out | Through 33 Ω to each input board |
| LRCK out (I2S0 master) | 33 | J3 | Out | Through 33 Ω to each input board |
| BCLK loop-back in (I2S1 slave) | 36 (SENSOR_VP) | J3 | In (input-only pin) | Short wire from GPIO25 at the board |
| LRCK loop-back in (I2S1 slave) | 39 (SENSOR_VN) | J3 | In (input-only pin) | Short wire from GPIO33 |
| Data in from input 1 (I2S0) | 35 | J3 | In (input-only pin) | |
| Data in from input 2 (I2S1) | 26 | J3 | In | |
| UART1 TX → input 1 RX | 17 | J4 | Out | |
| UART1 RX ← input 1 TX | 16 | J4 | In | |
| UART2 TX → input 2 RX | 19 | J4 | Out | |
| UART2 RX ← input 2 TX | 18 | J4 | In | |
| Power in | VSYS | J3 pin 19 | — | From the shared rail. See **Power** below |
| Ground | GND | J3 / J4 | — | |

All I2S signals land on J3 and both UARTs on J4, so the two harnesses stay separate.

**Pins deliberately avoided on this board:**

| Pin | Why |
|---|---|
| GPIO27 | Drives the onboard WS2812 RGB LED through R1 (0 Ω). Free it by removing R1 if ever needed |
| GPIO34 | Battery-voltage divider (200 k / 100 k) through R28 (0 Ω) |
| GPIO12, GPIO15 | Strapping pins (MTDI, MTDO); external levels at boot change boot behaviour |
| GPIO0, GPIO2, GPIO5 | Strapping pins, and GPIO0 is on the auto-download circuit |
| TXD0 / RXD0 | Console UART to the CH343P USB-serial chip; keep free for logs and flashing |
| SD0–SD3, CMD, CLK | Module flash |

Input-only GPIOs 34–39 have no internal pull resistors. That's fine here because every board is always powered together.

Assumed, not verified: GPIO16 and GPIO17 are free because the N4 variant has no PSRAM. Check against the module datasheet before building.

## Input board pins (Waveshare RP2350-USB-C, identical on both)

From Waveshare's schematic `RP2350-USB-C.pdf` (github.com/waveshareteam/RP2350-USB-C). The 18-pin header exposes GPIO0–10, GPIO26–29, 3V3, GND and VSYS.

| Signal | GPIO | Direction | Notes |
|---|---|---|---|
| BCLK in | 26 | In | From ESP32 GPIO25 via 33 Ω |
| LRCK in | 27 | In | From ESP32 GPIO33 via 33 Ω |
| DOUT | 28 | Out | To the ESP32 data-in pin (35 for board 1, 26 for board 2) |
| DIN (chain input) | 29 | In | For future expansion (another input board or an ADC). Tie to GND until used |
| UART TX | 4 | Out | UART1 TX → the ESP32 UART RX |
| UART RX | 5 | In | UART1 RX ← the ESP32 UART TX |
| Debug serial TX (PIO) | 3 | Out | Optional, to a USB-serial adapter |
| VBUS sense (optional) | any spare (0, 1, 2, 6–10) | In | From the board's `VSYS` pin via a 10k/20k divider. `VSYS` is raw VBUS here, so no solder jumper is needed. Probably unnecessary |

Not on the header, so no conflict: GPIO12/13 (second USB-C port, PIO-USB), GPIO16 (RGB LED).

**Erratum RP2350-E9** (input-mode pull-down latching / leakage) does not apply to any pin above: all are driven, and none relies on an internal pull-down. Confirm during bring-up.

## Power

**The RP2350-USB-C has no VBUS diode.** Its USB-C VBUS connects straight to the `VSYS` net and the `VSYS` header pin (verified from the schematic). Both of its USB-C ports share that net. So each input board needs **its own external Schottky** before the shared rail, or the two hosts' 5 V rails would be tied together.

```
Host 1 ─USB-C─▶ board 1 VSYS ──▶|── ┐
                                    ├── shared rail ──▶ ESP32 VSYS pin (J3-19)
Host 2 ─USB-C─▶ board 2 VSYS ──▶|── ┘
                (D1, D2: your Schottkys, cathode to the rail)
```

| From | To |
|---|---|
| Input board 1 `VSYS` | D1 anode |
| Input board 2 `VSYS` | D2 anode |
| D1 + D2 cathodes | Shared rail → ESP32 `VSYS` (J3-19), 22 µF + 0.1 µF near the ESP32 |
| All GND | All GND |

- **Diode orientation matters:** the banded end (cathode) goes to the rail. Check with a multimeter's diode range before powering anything.
- Each input board's own 3.3 V regulator (RT9013) is fed from its USB VBUS *before* the diode, so it keeps full headroom.
- The rail is about 4.25–5.2 V, typically ~4.65 V (estimate; review-notes #18): VBUS minus cable drop minus one Schottky drop. Measure it on the built box.
- **The ESP32 board's own USB-C is protected:** its VBUS reaches VSYS through D3 (MBR230, onboard). Plugging a laptop into it for flashing does not back-feed the rail past the input boards' diodes, and the rail does not appear on its USB-C. **You can flash the ESP32 with the box powered.**
- The ESP32 board's MP1605 converter accepts 2.3–5.5 V in (schematic note), covering the whole rail range with ~0.3 V to spare at the top.
- The ESP32 board's ETA6098 charger sits on the same VSYS net. With no battery fitted it should stay idle (estimate ~85%; its absolute-maximum ratings are unverified). Never fit a battery to its GH1.25 connector.
- **The second USB-C port on each input board is live on `VSYS`.** Anything plugged into it lands on that board's VBUS, on the host side of the diode. Leave both inner ports unused and unreachable inside the case.

## Mounting

- **Input boards are held by the enclosure's USB-C wall and cradle, not screws.** Neither the QT Py RP2040 (verified: no mounting holes in Adafruit's board file) nor the RP2350-USB-C is screw-mounted. This is unchanged by the board swap; only the cradle dimensions change.
- **ESP32 board:** the Feather V2 had two plated M2.5 holes. Whether the Waveshare dev kit has mounting holes is **unverified** — check the physical board or Waveshare's mechanical drawing.

## Parts at the split point (perfboard)

- **2 × Schottky diode** (e.g. 1N5817, SS14, or any low-Vf part rated ≥ 1 A): one per input board, `VSYS` → rail.
- **4 × 33 Ω:** BCLK → board 1, BCLK → board 2, LRCK → board 1, LRCK → board 2. Place them at the ESP32 end.
- The loop-back wires (GPIO25 → 36, GPIO33 → 39) connect before the resistors, right at the ESP32 board.
- Keep I2S runs under ~10 cm.

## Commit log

2026-09-24 Project scaffold: handoff, review notes, BOM
    Adds the design handoff, CLAUDE.md with working preferences, a BOM,
    and review notes covering USB-C CC resistors, the system clock choice,
    rail capacitance, VBUS-gated USB connect, and the RP2350 E9 erratum.
    Claude-Session: https://claude.ai/code/session_013NPxgfHkq3mEXAkrDqqxUQ
    [BOM.csv]
2026-09-24 Switch to USB-C RP2040 board exposed through enclosure wall
    Drops the micro-USB panel extensions from the BOM and records that the
    handoff's Pico-specific power and VBUS-sense details need rework.
    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
    [BOM.csv]
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2026-09-24 Add USB-C RP2040 board power-path comparison
    Verified from published Eagle schematics: QT Py RP2040, KB2040 and
    SparkFun Pro Micro RP2040 have an onboard VBUS Schottky and 5.1k CC
    resistors. RP2040-Zero ties 5V directly to VBUS.
    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
    [BOM.csv]
2026-09-24 Adopt QT Py RP2040: wiring map, review notes 8-12, BOM
    - hardware/wiring.md: QT Py pin map (GPIOs verified from schematic)
    - Review notes: volume Feature Unit needed for macOS, TinyUSB feedback
    API verified, UART debug, smaller gaps
    - BOM: QT Py, USB-serial adapter
    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
    [BOM.csv]
2026-09-24 Add whole-project viability review
    Judges the outcome rather than the handoff design: A/V sync limitation,
    headphone codec support vs TSA5001 aptX, input/output stage options,
    ranked risks, and a risk-first build order.
    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
2026-09-24 Viability review: generalize to any USB-C audio host and any BT sink
    Drop device-specific targeting. Add a latency breakdown by stage, the
    low-latency Bluetooth options a transmitter can offer, and output-stage
    options ranked as the latency lever, including a USB-host dongle path
    (TinyUSB audio host driver verified present; RP2040 runtime unverified).
    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
2026-09-24 Enclosure: USB-C wall + cradle test coupon for QT Py RP2040
    Parametric OpenSCAD coupon (wall with USB-C opening and overmold pocket,
    cradle, drop-in retaining key) using board and connector geometry from
    Adafruit's Eagle files. Includes exported STLs, preview renders, and a
    collision-check script (verified to catch an undersized opening).
    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
    [fit_checks.scad, usb_wall_test.scad, usb_wall_test_coupon.stl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]
2026-09-25 BOM: confirm QT Py PID 4900, list sellers for QT Py and TSA5001
    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
    [BOM.csv]
2026-09-25 Board comparison: add SB Components Micro RP2040 (no VBUS diode, no CC resistors)
    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
2026-09-28 Record decisions: ESP32 BT output, USB control channel, no case buttons
    Adds docs/decisions.md (decision log with open questions), updates the
    BOM (ESP32 Feather V2 in, TSA5001 to fallback, pairing button removed),
    README status, and CLAUDE.md precedence.
    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
    [BOM.csv]
2026-09-28 BOM: give fallback parts their own item numbers
    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
    [BOM.csv]
2026-09-28 BOM: parts for the ESP32 design; review note on power and pins
    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
    [BOM.csv]
2026-09-28 Feather V2 power: feed rail into BAT pin (schematic-verified)
    Adafruit's schematic shows the USB pin is raw VBUS of the Feather's own
    USB-C, so feeding it would back-feed flashing hosts. BAT reaches the
    regulator through the changeover P-FET without touching VBUS. Drop the
    external Schottky from the BOM.
    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
    [BOM.csv]
2026-09-28 Decide ESP32 hub: ESP32 mixes and owns the audio clock
    - hardware/wiring.md rewritten: ESP32 I2S0 master + I2S1 slave (clock
    loop-back wires), two UARTs to identical RP2040 slaves; pins checked
    against the Feather V2 and QT Py schematics
    - decisions.md: new entry, mixing-location question resolved
    - CLAUDE.md firmware layout, design-envelope baseline, review note #15
    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
2026-09-28 Add architecture doc; decide control channel (USB network + self-served page)
    docs/architecture.md: roles, audio path and clock sync, control path
    (USB network adapter + web page on the QT Py, UART relay, ESP32 as
    single source of truth), firmware updates, risks, bring-up order.
    decisions.md, README and CLAUDE.md updated to match.
    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
2026-09-28 Verify ESP32-A2DP volume/reconnect support; find 44.1 kHz source limit
    Reconnect: supported, last address saved in NVS. Volume: absolute-volume
    notifications handled but the default volume control scales audio too
    (use A2DPNoVolumeControl); passthrough VOL keys need our handler.
    ESP-IDF's A2DP source offers SBC at 44.1 kHz only, so the box should run
    at 44.1 kHz end to end (open question for the owner).
    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
2026-09-28 Design envelope: fix host sample-rate row for 44.1 kHz
    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
2026-09-28 Review note #17: full Feather V2 power check; charger chip soft spot
    Regulator, FET path and ADC divider are fine on the 4.6-4.8 V rail. The
    MCP73831 charger sees 0.4-0.6 V above its 4.2 V design point on VBAT and
    its abs-max row is ambiguous; list options (remove U3 recommended).
    Correct #14: charger back-feed likely can't run the whole box.
    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
2026-09-28 Derive the shared rail voltage instead of assuming ~4.6-4.8 V
    Review note #18: rail = host VBUS (4.75-5.5 V, USB-C vSafe5V) minus
    cable drop minus the QT Py's NSR0320 drop, giving about 4.25-5.2 V,
    typically ~4.65 V. Update #14, #17, wiring, board comparison and the
    design envelope to match. Correct #17's regulator-heat claim and lower
    the charger-chip confidence to ~75% for the rail's high end.
    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
2026-09-28 Review note #19: Adafruit advises against non-battery power on BAT
    Adafruit's Feather power pages warn that alkaline/NiMH on the battery
    port destroys the LiPoly charger and that Feathers aren't designed for
    external supplies. Record this, withdraw the ~75% "leave as is" estimate,
    and add the charger-chip choice to the decision log as an open question.
    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
2026-09-29 Switch boards: RP2350-USB-C inputs, Waveshare ESP32 dev kit
    Inputs move from the Adafruit QT Py RP2040 to the Waveshare RP2350-USB-C
    for its 520 KB RAM, with an owner-supplied Schottky per board because it
    has no onboard VBUS diode. The ESP32 moves from the Feather V2, which has
    no supported non-battery supply route, to the Waveshare
    ESP32-DEV-KIT-WROOM-32E-N4, fed from the rail via its VSYS pin.
    Both pin maps redone from the schematics: the ESP32 board uses GPIO27 for
    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
    [BOM.csv]
2026-09-29 Correct the mounting note: input boards were never screw-mounted
    The QT Py RP2040 has no mounting holes either (verified from Adafruit's
    board file), so the RP2350-USB-C's castellated edge changes nothing about
    how input boards are held - the USB-C wall and cradle do that, and only
    the cradle dimensions move. The M2.5 hardware was for the Feather V2 and
    the lid; whether the Waveshare ESP32 dev kit has holes is unverified.
    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
    [BOM.csv]
2026-10-11 Resolve the GPIO16/17 assumption: schematic names the N4 module
    The Waveshare schematic labels U1 as ESP32-WROOM-32E-N4, so it is the
    exact variant being ordered and has no PSRAM. GPIO16/17 are free and on
    header J4.
    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
2026-10-11 Input board: silkscreen says 5V, not VSYS; record its dimensions
    Waveshare's pinout drawing labels the raw-VBUS pin 5V even though the
    schematic net is VSYS, so the wiring doc now uses the silkscreen name for
    the input boards and keeps VSYS for the ESP32 board, which really is
    labelled that. Also records the dimensioned drawing from Waveshare's repo:
    33.00 x 17.50 mm, R2.00 corners, 8.90 mm USB-C shell centred.
    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
2026-10-11 Enclosure: rebuild the test coupon for two RP2350-USB-C boards
    Rework the coupon for the chosen side-by-side layout: one wall with two
    USB-C openings and two cradles, so the print can show whether two cable
    overmolds foul each other. Board geometry comes from Waveshare's
    dimensioned drawings (33.00 x 17.50 input board; 53.80 x 27.94 ESP32
    board with four mounting holes), which also resolves the open
    mounting-hole question.
    The clip is redesigned: this board has a second USB-C connector on its
    inner end, so the clip now has a window clear of it and bears on the full
    PCB back edge instead of two corners.
    Two collision checks were passing for the wrong reason - a probe that
    spanned the whole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
2026-10-11 Enclosure: drop the inner-end clip, leaving the staple as sole retainer
    The clip was a push-in backstop shaped around the board's unused inner
    USB-C connector. The staple in the retention notches already takes that
    load, so the clip was redundant - and worse, fitting it meant the coupon
    could not answer whether the notches alone hold under plug-in force,
    which is the open question.
    Removing it also deletes the cradle's back posts and key slots, so the
    coupon is 1.4 mm shorter and a lot easier to read. The board's inner end
    is now unrestrained in Z; the lid does that job in the full box.
    Claude-Session: https://claude.ai/code/session_013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
2026-10-22 Enclosure: retain the boards on floor nubs, drop the staple
    Owner has the boards: the staple did not work in practice. Replace it
    with two nubs rising from the cradle floor into the PCB's edge notches,
    which puts plug-in and pull-out load into the board edge-on and leaves
    no loose parts - the coupon is now a single print.
    Fixed nubs rule out the old slide-forward assembly, since the notch
    would have to travel over the nub through solid PCB, and any nub short
    enough to allow the slide leaves ~1.5 mm of play. So each port opening
    is slotted open to the top of the wall and the board drops straight
    down; the lid caps the slots in the full box.
    New check sweeps the board and both USB shells upw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
2026-10-22 Enclosure: flush outer port, so the solid wall comes back
    Measured on the real board: the exposed USB-C shell is flush with the
    board edge, only the inner programming port is proud. A flush shell never
    has to thread into the wall, so the drop slot added for straight-down
    assembly is unnecessary - the port opening goes back to a closed,
    shell-shaped hole in a solid wall and the board still drops onto the nubs.
    usb_over splits into usb_over_out (0.00, measured) and usb_over_in (1.00,
    still assumed). The drop test now encodes the dependency: making the outer
    shell proud again fails it.
    mouth_recess becomes the explicit dial between a shell-shaped opening and
    full plug insertion, defaulting to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
2026-10-22 Enclosure: model the full box, everything mounted to the base
    Layout per the owner: two RP2350 input boards in cradles at the front on
    their notch nubs, the ESP32 flat on the base behind them on four
    standoffs through its own mounting holes, and a lid whose only job is to
    press the RP boards down. Four M3 self-tapping screws hold the halves.
    About 64.6 x 79.7 x 15.2 mm.
    Board numbers and enclosure fit values move into a new shared
    boards.scad, so the coupon and the box cannot drift apart - duplicated
    dimensions have twice made a check pass for the wrong reason here.
    The lid may only touch the board where there are no castellated pads, so
    a pad_zone() check models the strip where pads and s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
2026-10-22 Add a visual wiring guide; note PETG as the enclosure material
    hardware/wiring-guide.html is a bench reference: four top-view layout
    drawings (placement, power, I2S, UART) rather than schematics, plus a
    tickable 26-joint checklist and a table of where each of the ten inline
    parts mounts. Colour never carries meaning alone - each harness also has
    its own line style and every wire is labelled.
    Two assembly facts the drawings surfaced: both input boards must face the
    same way since a PCB cannot be mirrored, so their pin rows repeat
    power/I2S then UART; and the ESP32 should be mounted with J3 facing the
    input boards to keep the clock runs short.
    Also records that the owner prints in PETG, so t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
2026-10-24 Wiring guide: re-imagine the layout around JST connectors
    Adding a connector to every board changes the topology, not just the
    parts list: a signal can only reach a connector if it lands on the board
    carrying that connector, so the perfboard stops being a component carrier
    and becomes the backplane all 25 wires pass through. That reverses
    Figure 5's "audio and UART stay point-to-point".
    Four cables, one per board plus a second for the ESP32 since its two
    headers face opposite ways: J1/J2 7-way on the hub's short edges fed up
    the side channels, J3 6-way on the back edge as the shortest run in the
    box, J4 5-way routed around the ESP32's USB-C end rather than past the
    antenna. Figure 6 and a p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
2026-10-24 Wiring guide: redraw the hub for connectors
    The previous commit added the box-level connector layout but left the
    hole-by-hole perfboard drawing as the hardwired version, still showing
    twelve bare-wire landings. Redrawn.
    The hub is now 21 x 8 holes (~54 x 21 mm): a 7-way connector on each
    short edge facing the input boards, a 6-way and a 5-way on the back edge
    facing the ESP32, with their bodies shown as dashed outlines over the
    holes they cover and each pin named beside its row. Ground and rail buses
    on rows 5-6, two clock buses on row 8 with a gap at column 8.
    The seventeen underside links are given as a table rather than drawn -
    that many crossing lines on this grid is unreadable, and a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
2026-10-24 Close three measurements from the real hardware
    esp_top_h 5.00 -> 4.50 (owner, by eye), which drops the enclosure from
    15.2 to 14.7 mm tall. esp_hole_dia stays 2.60 with M2.5 confirmed as the
    right screw.
    The ESP32's power pin is silkscreened 5V, not VSYS. Both boards label
    that net 5V even though both schematics call it VSYS, so the naming trap
    recorded earlier does not exist - that claim came from reading the
    schematic, not the board. wiring.md and the wiring guide corrected.
    Box checks re-run: 9 guards, 19 collisions, all pass. STLs and previews
    re-exported.
    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
2026-10-24 Figures: read board geometry from boards.scad instead of copying it
    The owner pointed out that the figures still draw both USB-C shells sticking
    out past the PCB edge. Only the inner programming port is proud; the exposed
    port at the notch end is flush, in fact a fraction of a mm recessed. He had
    corrected this before.
    That correction did land - enclosure/boards.scad has carried
    usb_over_out = 0.00 since, and the enclosure is built on it. The figures
    missed it because pictorial.py kept its own copy of the board geometry and
    hardcoded a 1.0 mm overhang on both ends, which is exactly what the header of
    boards.scad forbids:
    Every file that needs a board number includes THIS file. Nothing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
2026-10-26 Carrier board: schematic generated from a verified netlist
    First piece of the carrier PCB that replaces the hand-wired loom. Schematic
    only -- no footprints, no layout, nothing ordered.
    netlist.py is the single source of truth: parts, pin maps, nets, and what is
    deliberately left unconnected. gen_sch.py emits the KiCad schematic from it
    and gen_table.py emits CONNECTIONS.md, so the drawing and the table cannot
    drift apart. This follows the same rule as enclosure/boards.scad - exactly
    one copy of every number.
    Connectivity is carried by global labels rather than drawn wires. That is
    easier to read for a carrier, and much easier to verify: check_netlist.py
    re-extracts the netlist from the ge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
2026-10-26 Record that both modules are flat underneath
    Owner, boards in hand. Neither Waveshare drawing shows the underside, so
    esp_bot_h 0.50 and under_clear 1.5 were both guesses.
    esp_bot_h is now 0.00, measured. under_clear keeps its value but not its
    meaning: there are no underside parts to clear, only solder fillets on the
    castellated pads in the hand-wired build, and 1.5 mm is far more than those
    need. Dropping it to 0 would shorten the box by 1.5 mm, remove the cradle
    ledges and invalidate the printed coupon, so it is left alone pending the
    owner, with the reasoning in review-notes #23.
    This is what makes the carrier PCB possible: edge-soldering a castellated
    module requires it to sit flat.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
2026-10-26 Carrier board: outline and placement, 58 x 74 mm, unrouted
    gen_pcb.py places all 18 parts on a 58 x 74 mm outline that fits the current
    enclosure interior (59.8 x 74.94). The two input boards sit with their
    exposed USB-C ports exactly on the front edge, so they still meet the port
    wall; the ESP32 is turned 180 degrees so header J3 faces them, which puts the
    four clock resistors hard against its J3 row at the driving end.
    NOT ROUTED, on purpose. KiCad 7's kicad-cli has no DRC subcommand - it
    arrived in 8, and only 7 is packaged here - so generated tracks could not be
    checked for clearance. This board also has a 2.4 GHz antenna and clock
    traces, where layout quality is a judgement call. Routi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
2026-10-26 Measure routing headroom; withdraw the "too dense" claim
    I had called the carrier dense and routing unproven on the strength of "81%
    courtyard area". That reads the figure wrong. A courtyard is keep-out for
    other COMPONENTS, not for copper. Each module touches the board only at its
    edge pads and is flat underneath (review-notes #23), so the entire area under
    both RP boards and the ESP32 is available for traces on both layers.
    check_routing.py measures it from the actual placement: ~930 mm of minimum
    trace over 23 nets, about 9% of the copper at 0.4 mm trace on 0.4 mm
    clearance. Worst I2S net is BCLK at 37 mm against the <100 mm rule in
    wiring.md. No connected pad falls inside the antenna ke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
2026-10-26 Fix the rotation transform; add a check that does not share our arithmetic
    The transform placing a rotated footprint was wrong for 90 degrees: it used
    y' = +x where KiCad uses y' = -x. Five parts were out of position by up to
    7.6 mm, with D1 and D2 partly off the board.
    Every existing check said OK. check_pcb.py reuses gen_pcb's geometry on
    purpose, so the generator and the check cannot drift apart - but that also
    means a bug in the SHARED code is invisible to both. They were doing the same
    wrong arithmetic and agreeing with each other.
    check_pads_vs_kicad.py closes that hole by taking KiCad's word for it. It
    renders F.Cu plus Edge.Cuts, finds the centroid of every copper blob by flood
    fil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
2026-10-26 Route the carrier: 23/23 nets, verified clean
    route.py is a grid A* router over two layers; check_clearance.py measures the
    result edge to edge against the 0.25 mm rule for every same-layer pair of
    different nets. 358 segments, 74 vias, 1185 mm of track against a 932 mm
    theoretical minimum. Trace 0.40 mm on 0.25 mm clearance, loose enough for any
    fab.
    The board grew from 58 to 64 mm wide. At 58 the two input boards left a
    2.2 mm channel between them and six of input 2's nets need access from that
    side, because both modules face the same way so its power and I2S edge points
    into the gap. Two nets could not be routed and no amount of router tuning was
    going to fix a channel that is physically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
2026-10-26 Audit the carrier board: do not order it yet
    Ran KiCad's own DRC for the first time. It was available all along:
    kicad-cli in KiCad 7 has no DRC subcommand, but pcbnew.WriteDRCReport has
    existed since 7.0 and imports from /usr/bin/python3. This project said for
    several sessions that no DRC was available, having only checked the CLI.
    drc.py now runs it reproducibly on a copy of the board with pad nets assigned.
    Two errors would stop the board working at all:
    - Both Schottky diodes are reversed. KiCad's DO-41 footprint marks pad 1 as
    the cathode; netlist.py puts the anode there. Built to the silkscreen, the
    rail never gets power. check_netlist.py compared pad-number sets and could
    not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
2026-10-26 Carrier fix order steps 1-4: KiCad DRC clean, routed with GND pours
    Works through AUDIT.md's fix order. Docs and the wiring guide follow in
    the next commit; until then README/wiring.md still describe the old board.
    1. Diodes: netlist mapped A=1, the footprint's pad 1 is K (rect pad, "K"
    silk). Fixed, and check_netlist now checks polarity against the
    footprint itself, so the mistake fails the build.
    2. Netlist: BCLK/LRCK loop-backs moved off IO36/IO39 (ADC erratum, glitches
    during A2DP) to IO13/IO32; 1k in series with every line the ESP32
    drives into an input board (back-feed into an unpowered RP2350); 4k7
    pulldowns on GP29, 100k on AUD1; ESP32 pads under the overhang marked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
2026-10-26 Carrier fix order step 5: docs, BOM and wiring guide match the fixed design
    - carrier/README.md rewritten for the board as it now is: L-shaped
    70.0 x 79.6 mm, routed, GND pours, KiCad DRC as the gate, and a table of
    deliberate breaks each check catches. The DO-NOT-ORDER banner becomes a
    hold: antenna clearance (AUDIT.md #21) and an untested I2S loop-back.
    - AUDIT.md: status of all 20 findings with how each was verified, plus a
    new open item #21: the antenna's front side has copper ~5-6 mm away,
    against Espressif's 15 mm. Options and a recommendation, owner decides.
    - wiring.md: loop-backs on IO13/IO32 (IO36/39 avoided, erratum), 1k series
    on clocks and UART TX, pull-downs on AUD1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
2026-10-26 Owner decision: keep carrier layout A; close AUDIT.md #21
    The owner accepted the current 70.0 x 79.6 mm L with 6.55 mm of copper in
    front of the antenna (Espressif asks for 15 mm). Recorded in decisions.md;
    AUDIT.md, the carrier README and the BOM no longer hold the order on it.
    Option C stays documented as the fix if Bluetooth range proves short.
    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
2026-10-27 Docs: native USB to the hosts, new ESP32 pin map, carrier layout rules
    - review-notes #25: the inward "programming" port is the RP2350's native
    USB, so the hosts had been on PIO-USB; boards turned 180 degrees, and what
    that changes (firmware, programming, plug forces, enclosure, loom guide).
    - decisions.md: the turn, and the S layout rules with their pin swaps.
    - wiring.md: new ESP32 pin table and loop-backs, which port is which,
    programming with everything soldered, R7 on AUD2, standing R1/R3, and the
    loom box's notch/flush-port assumptions flagged out of date.
    - carrier README rewritten for the current board: layout rules and where
    everything sits, Freerouting and the committed r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
